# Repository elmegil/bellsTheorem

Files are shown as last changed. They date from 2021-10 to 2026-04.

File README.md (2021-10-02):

# bellsTheorem
[]

Bell's theorem is a proof that quantum physics is incompatible with local hidden variable theories.  The summary on Wikipedia is quite good if you’re interested in the quantum physics aspects of the theorem.

The proof is sometimes demonstrated by the use of multiple polarized lenses, as in this video:

https://www.youtube.com/watch?v=zcqZHYo7ONs&t=337s

What’s interesting is that with 3 or more polarized lenses, the behavior does not match what you might expect, namely that lens 1 reduces the light by a certain percentage, lens 2 reduces it further, and lens 3 reduces it even further, in a linear fashion.  If lens 3 and lens 1 are 90 degrees from each other, with nothing else involved, essentially no light gets through.  But if you insert lens 2 at a 45 degree angle to both of the others, suddenly there IS light getting through.  You’d expect that if 3 after 1 always blocks all the light, that would be true no matter what you put between the two.

A highly simplified explanation of this has to do with the fact that light is made up of photons, which are quantum objects.  Quantum objects behave probabilistically but ultimately are either there or not.  Photons going from lens 1 to lens 3 aren’t reduced in energy, they simply don’t pass both lenses.  However, going from one lens to one at 45 degrees only reduces the probability of photos passing by 50%.  In the process of going through, those photons then match the orientation of the second lens.  So when they get to a third lens, there is only a 45 degree angle difference there as well, and so 50% of the original 50%, or 25% of the original light, still passes through.

The rules for photons passing through polarized lenses basically are a probability that is determined entirely by the two lenses directly adjacent to the path of travel.  Any previous or subsequent lenses  aren’t considered except as a chained operation.  So with lens 1 at 0 degrees, lens 2 at 45, and lens 3 at 90 degrees (or 45 degrees from lens 2), the overall probability of a photon going from the start to the finish is 50% x 50%, or 25%.

Making things slightly weirder, the probabilities aren’t linear.  They follow a cosine squared relationship.  A photon passing through a pair of lenses at 22.5 degrees from each other is considerably more likely to pass through than the linear expectation of 75%.  In fact it’s about 85%.

============================================================================

Nyles Miszczyk on Facebook asked whether there were any modules that could process control voltages in this way.  There do not appear to be, but the idea was intriguing enough to give it a shot.  And that’s where this module comes from.

# Operational Notes

There is a single input voltage to be processed, which is normalled to +12V.  There are 4 encoders which represent the relative positions of four lenses, first to a “main” lens behind them all, and then relative to each other.  They’re arranged in a square pattern, and the input “light” (really the voltage) is processed as it goes through a single lens at 0 degrees, and then each subsequent lens.  Each of the combinations of lenses has a related output, so each of A, B, C, and D have an output that is only related to their individual angles relative to 0.  Each of AB, BC, CD, and DA has an output related to each of the intervening angles, as in the example described above; so for AB the voltage is reduced by whatever the probability is between 0 degrees and angle A, and then further reduced by whatever the probability is between the angles of A and B.  ABC, BCD, CDA, and DAB then follow the same rules for three lenses, and finally ABCD extends the process through all 4 lenses.

In addition to the encoders, each of the 4 lenses has a CV that is also related to its angle, added to the angle as set up by the encoder.  The 0 - 10V range maps to 180 degrees of rotation (positive only… need to consider doing otherwise).

On first power up, the lenses are reset to 0 degrees (but they should retain the last known state).  You can press each encoder to reset it to zero so that it’s at a known state.  If you do this by accident, pressing the encoder again takes you back to the saved state.  HOWEVER, if you zero out this way and then change things, you do do NOT save the new angle when you press again -- you just go back to the saved state, and pressing one more time takes you back to zero.

Voltage ranges: the current implementation limits inputs to 0-10V and each output will only generate 0-10V.  (and even that not very precisely).  A future revision may allow processing of bipolar input voltages, although this very likely will reduce the overall resolution.  Each input should be able to tolerate any normal Eurorack voltages outside this range (-12V to +12V), but they will be clamped at 0-10V.

Encoders:  the encoders’ positions are NOT directly mapped to the angle.  Most encoders only have about 24 steps (some have more, but none have 360 steps).  That did not seem to be a good resolution because each step would be 15 degrees.  I have mapped the encoders so that each step is 2 degrees of angle; this is why the press to reset is important so you can get back to a known angle. -- need to decide about CVs… 0 - 10V … is that 0 - 90 degrees?  0 - 180?  0 - 360?  Maybe consider 30 step encoders that do map the angle?  Is there any way to set up to display the angle, circle of LEDs on each encoder?  Is there sufficient space/bandwidth to update them?

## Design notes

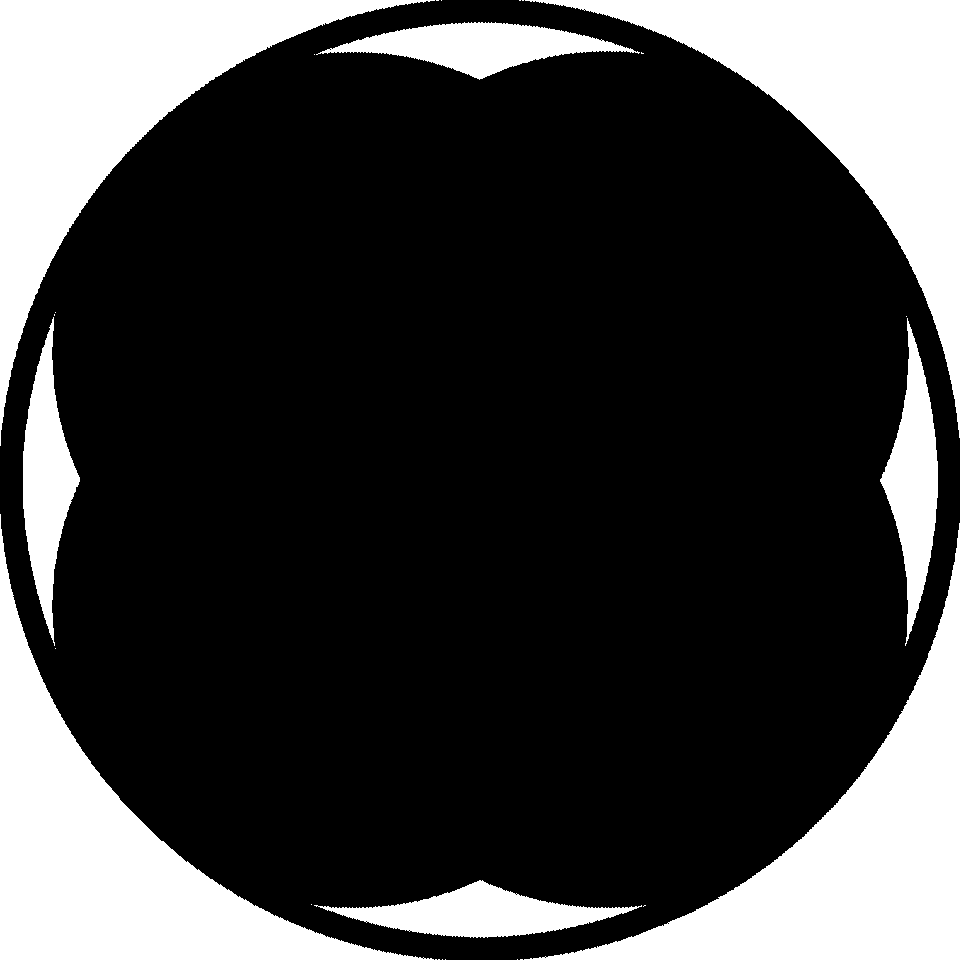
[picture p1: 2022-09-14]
images/bells-venn-trefoil-filled.bmp

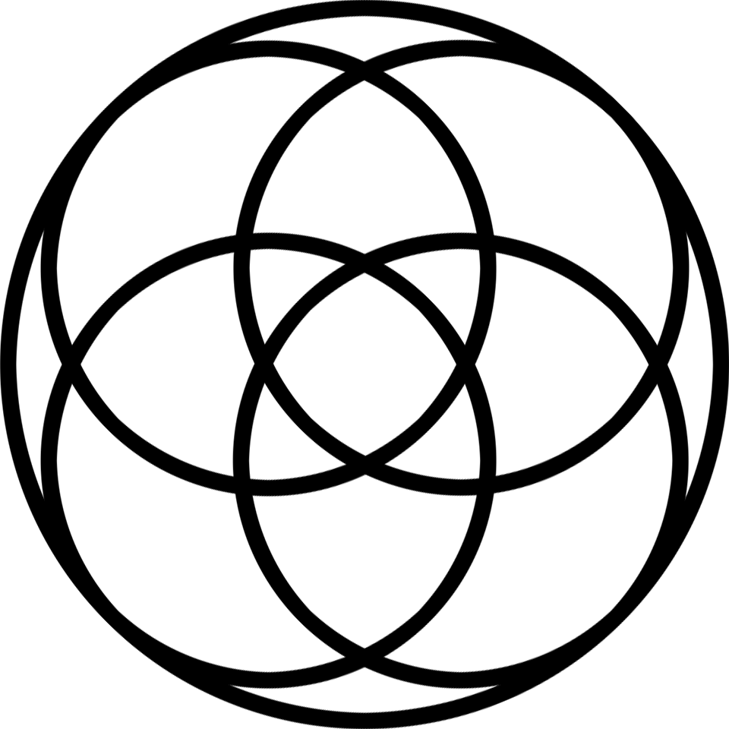
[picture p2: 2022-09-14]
images/bells-venn-trefoil.bmp

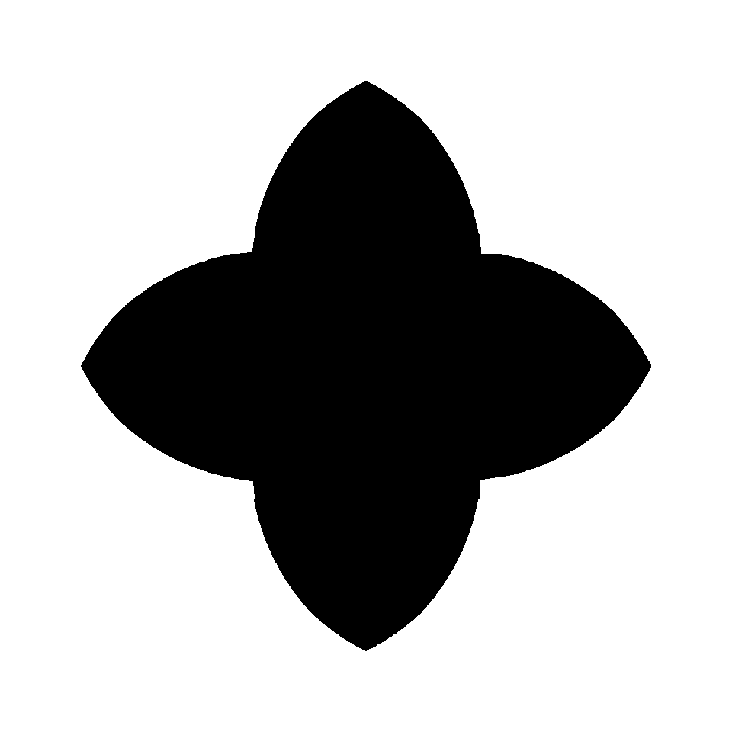
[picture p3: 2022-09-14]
images/bells-venn-trefoil-inside.bmp

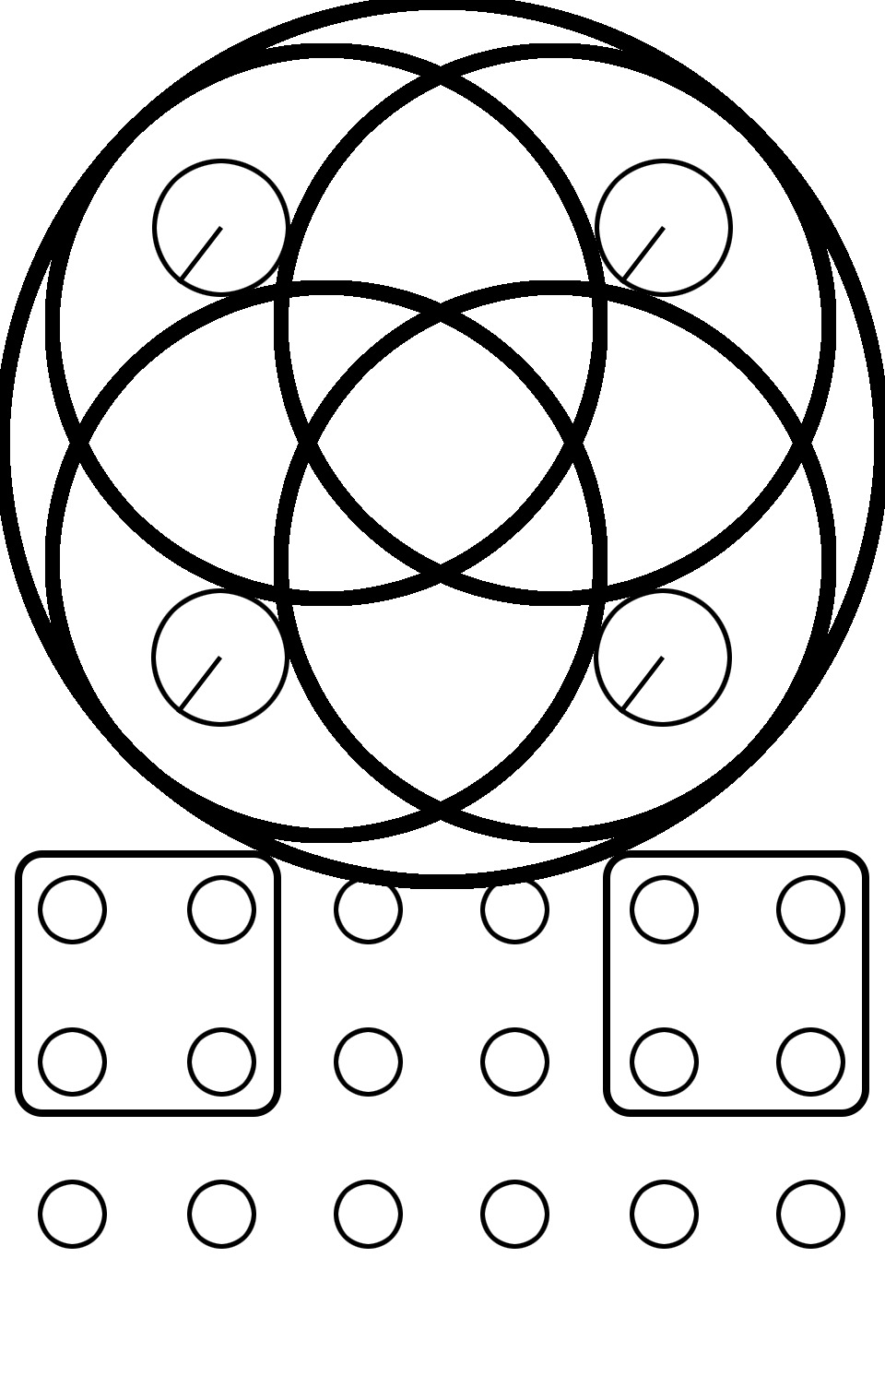
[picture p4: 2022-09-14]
images/bells-venn.jpg

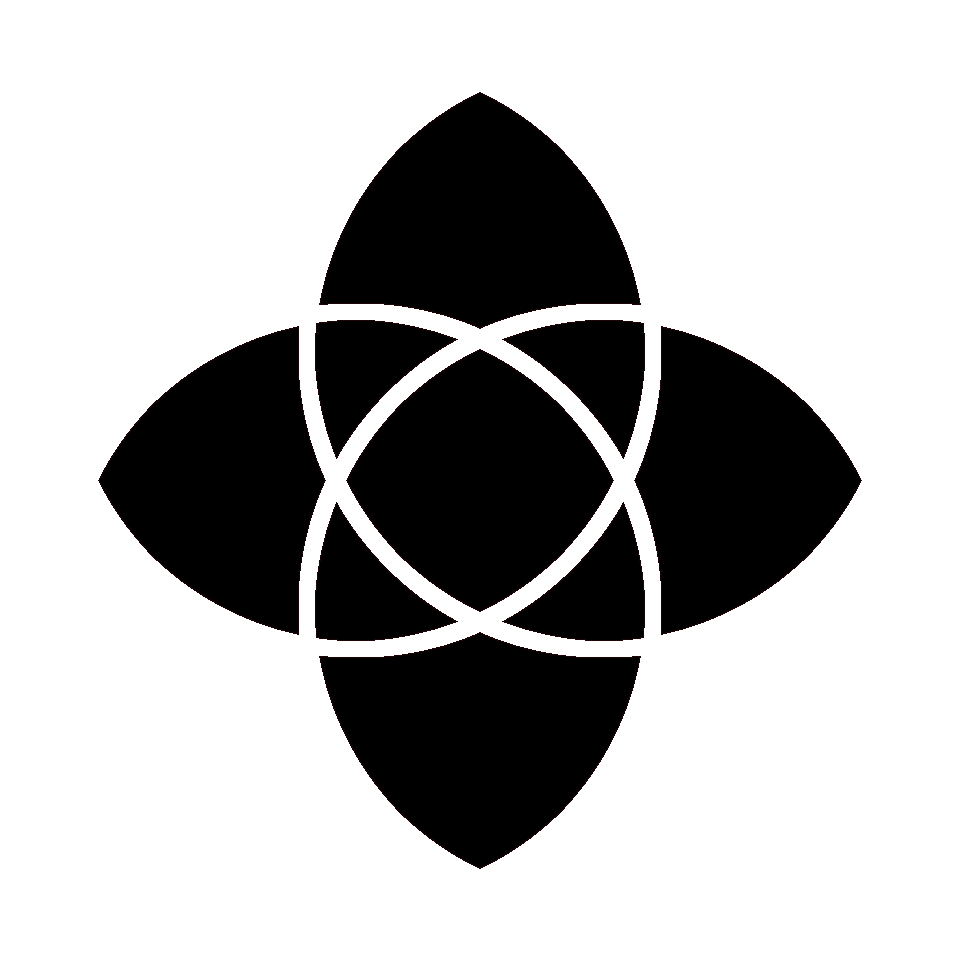
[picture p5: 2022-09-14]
images/bells-venn-trefoil-mask.bmp

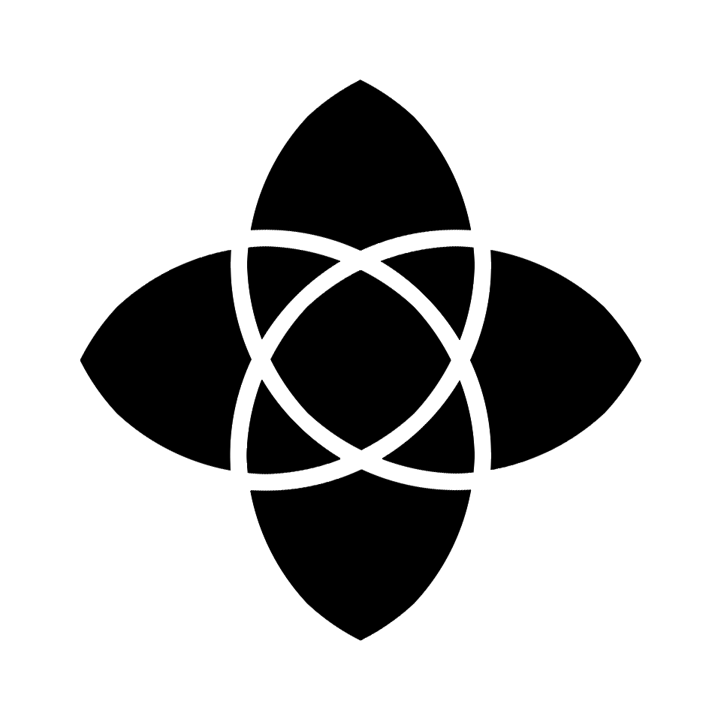
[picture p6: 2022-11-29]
images/bells-theorem-trefoil-mask2.bmp

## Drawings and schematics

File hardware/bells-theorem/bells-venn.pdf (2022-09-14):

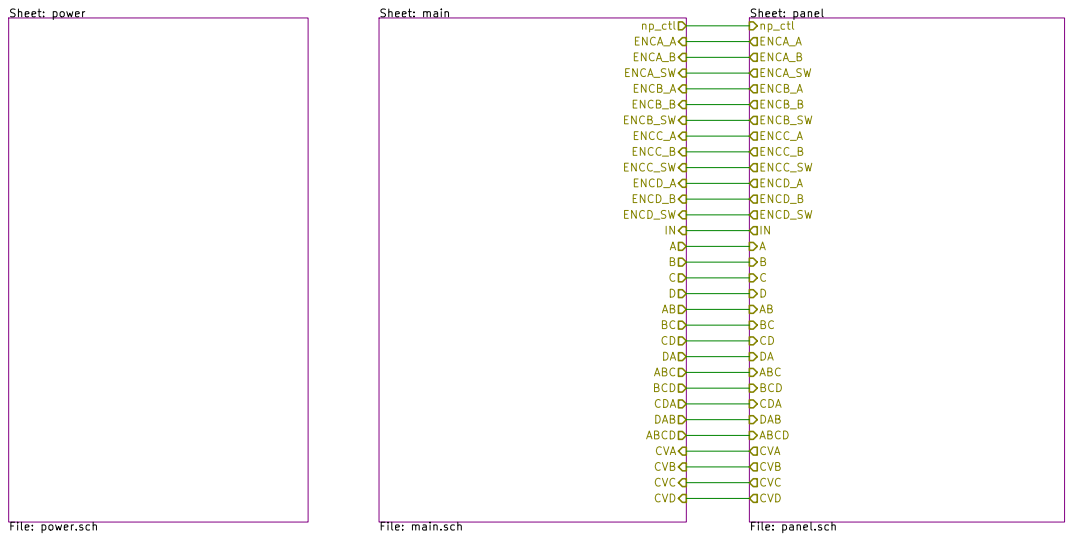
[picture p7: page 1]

File: bells-venn.sch Sheet: / re-layout attempting to use SMD and all in one PCB

Id: 1/8 Title: Hexinverter Postman

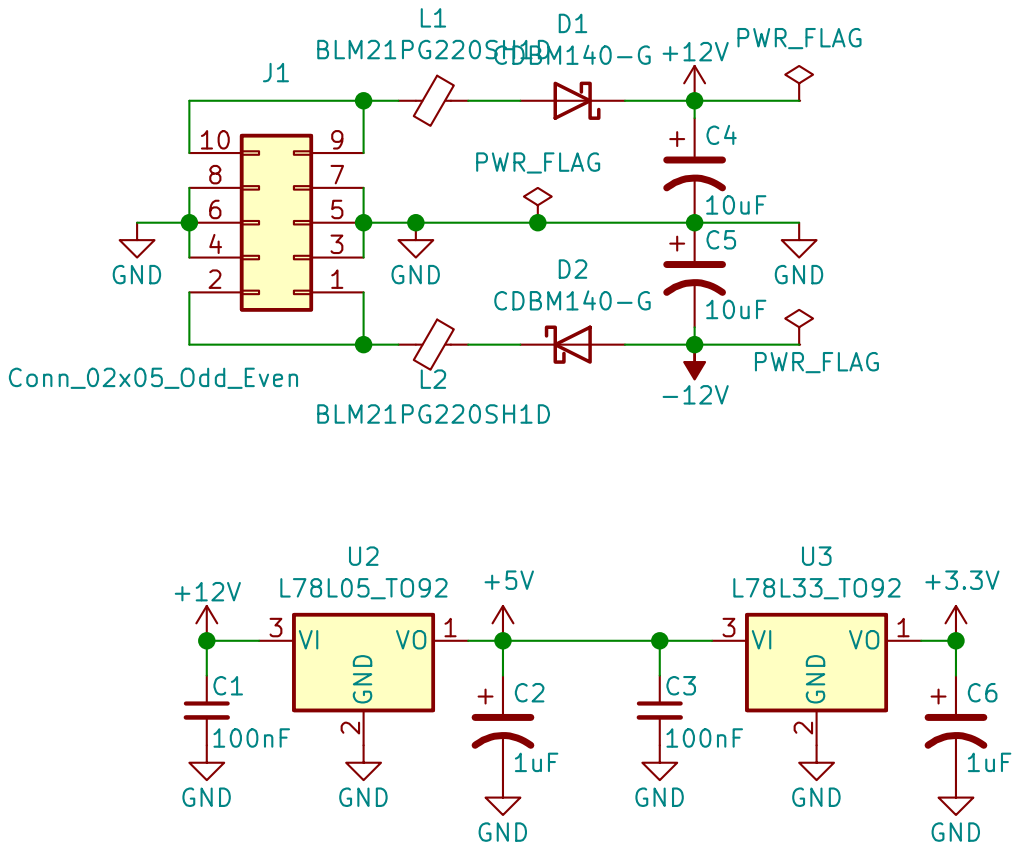
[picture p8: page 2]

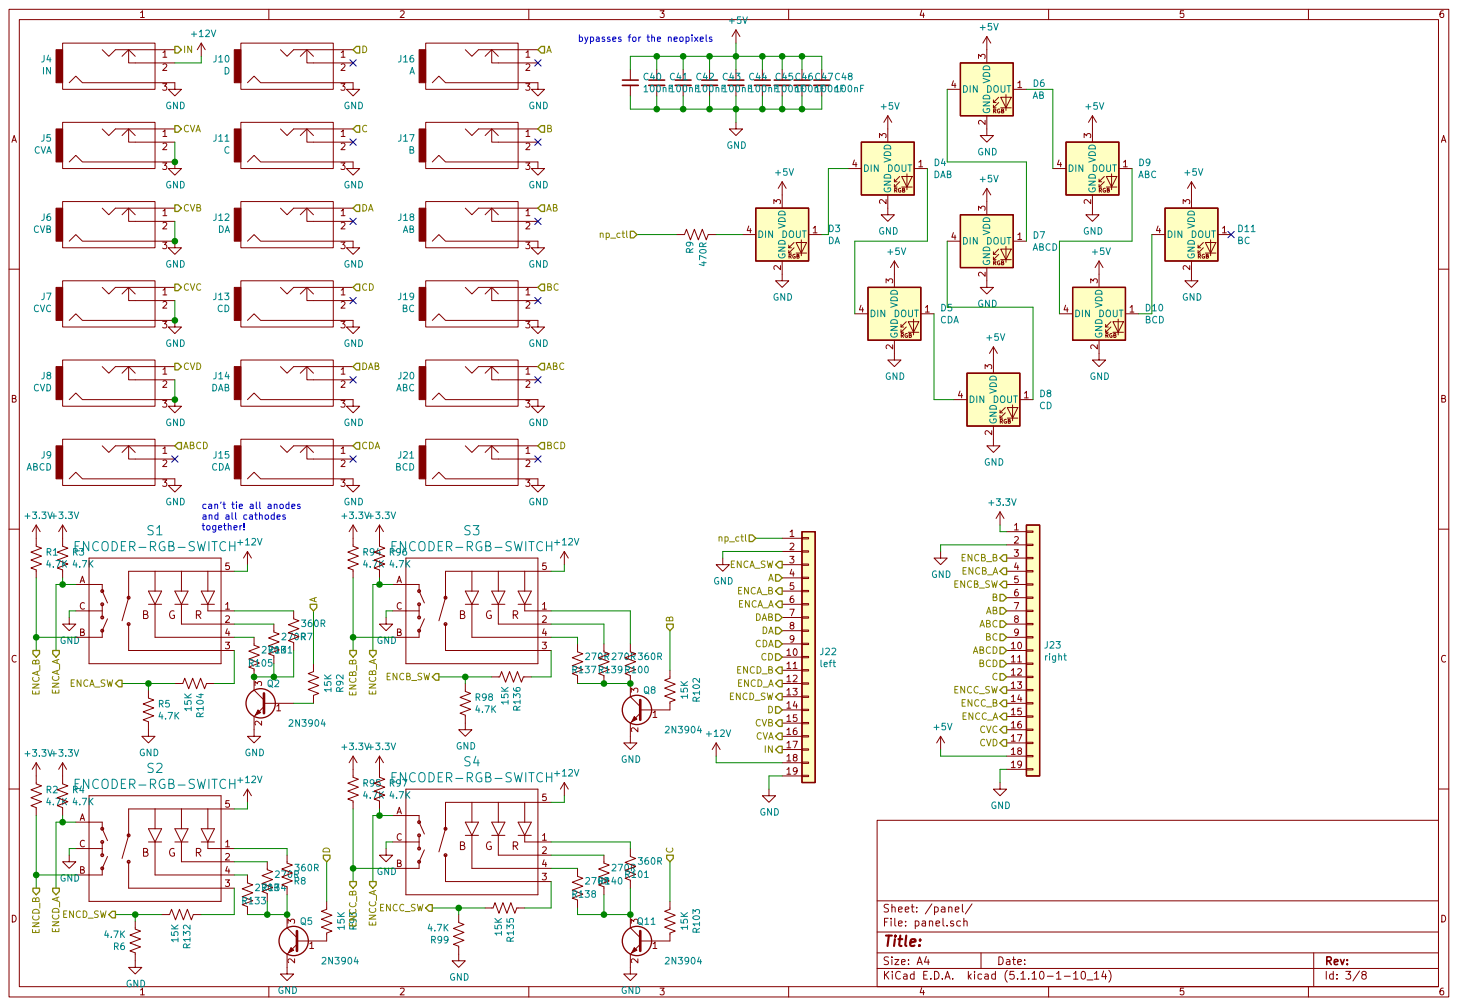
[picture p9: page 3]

cant tie all anodes and all cathodes

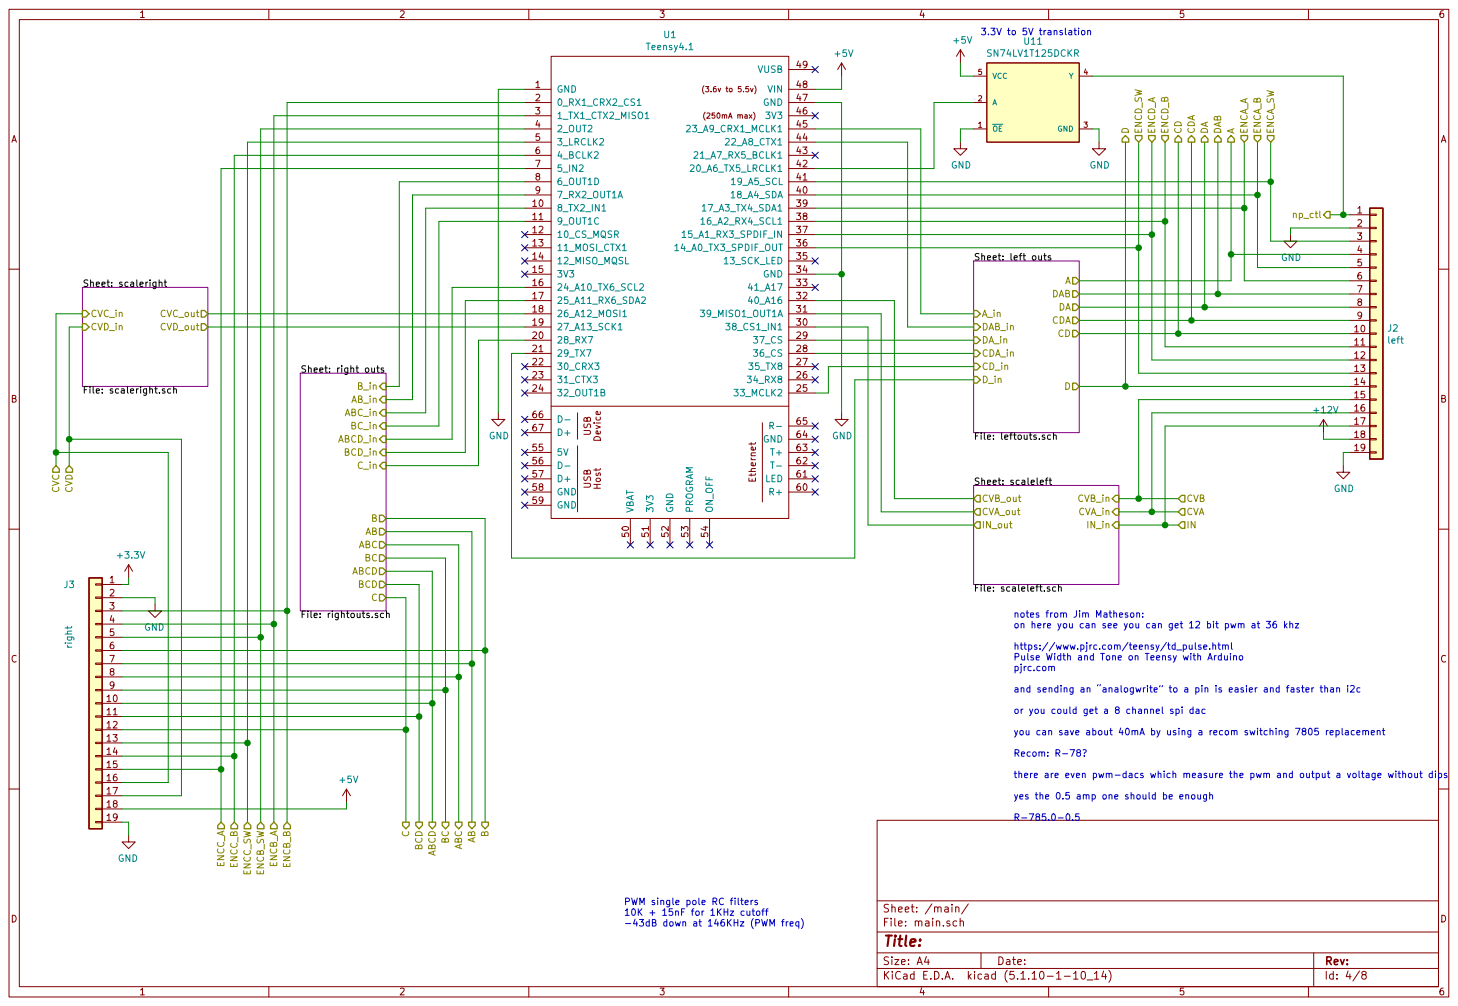
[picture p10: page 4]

7_RX2_OUT1A 9 GND 1

9_OUT1C 11 | | | left GND
6_OUT1D 8

10_CS_MQSR 12

25_A11_RX6_SDA2 17
26_A12_MOSI1 18
27_A13_SCK1 19
28_RX7 20
29_TX7 21

10
11

notes from Jim Matheson: on here you can see you can get 12 bit pwm at 36 khz

https://www.pjrc.com/teensy/td_pulse.html
Pulse Width and Tone on Teensy with Arduino
pjrc.com

12
13
14
15
16

and sending an analogwrite to a pin is easier and faster than i2c

or you could get a 8 channel spi dac

you can save about 40mA by using a recom switching 7805 replacement Recom: R-78?

there are even pwm-dacs which measure the pwm and output a voltage without dips

yes the 0.5 amp one should be enough R-785.0-0.5 PWM single pole RC filters 10K + 15nF for 1KHz cutoff -43dB down at 146KHz (PWM freq)

Id: 4/8 Title: File: main.sch Sheet: /main/

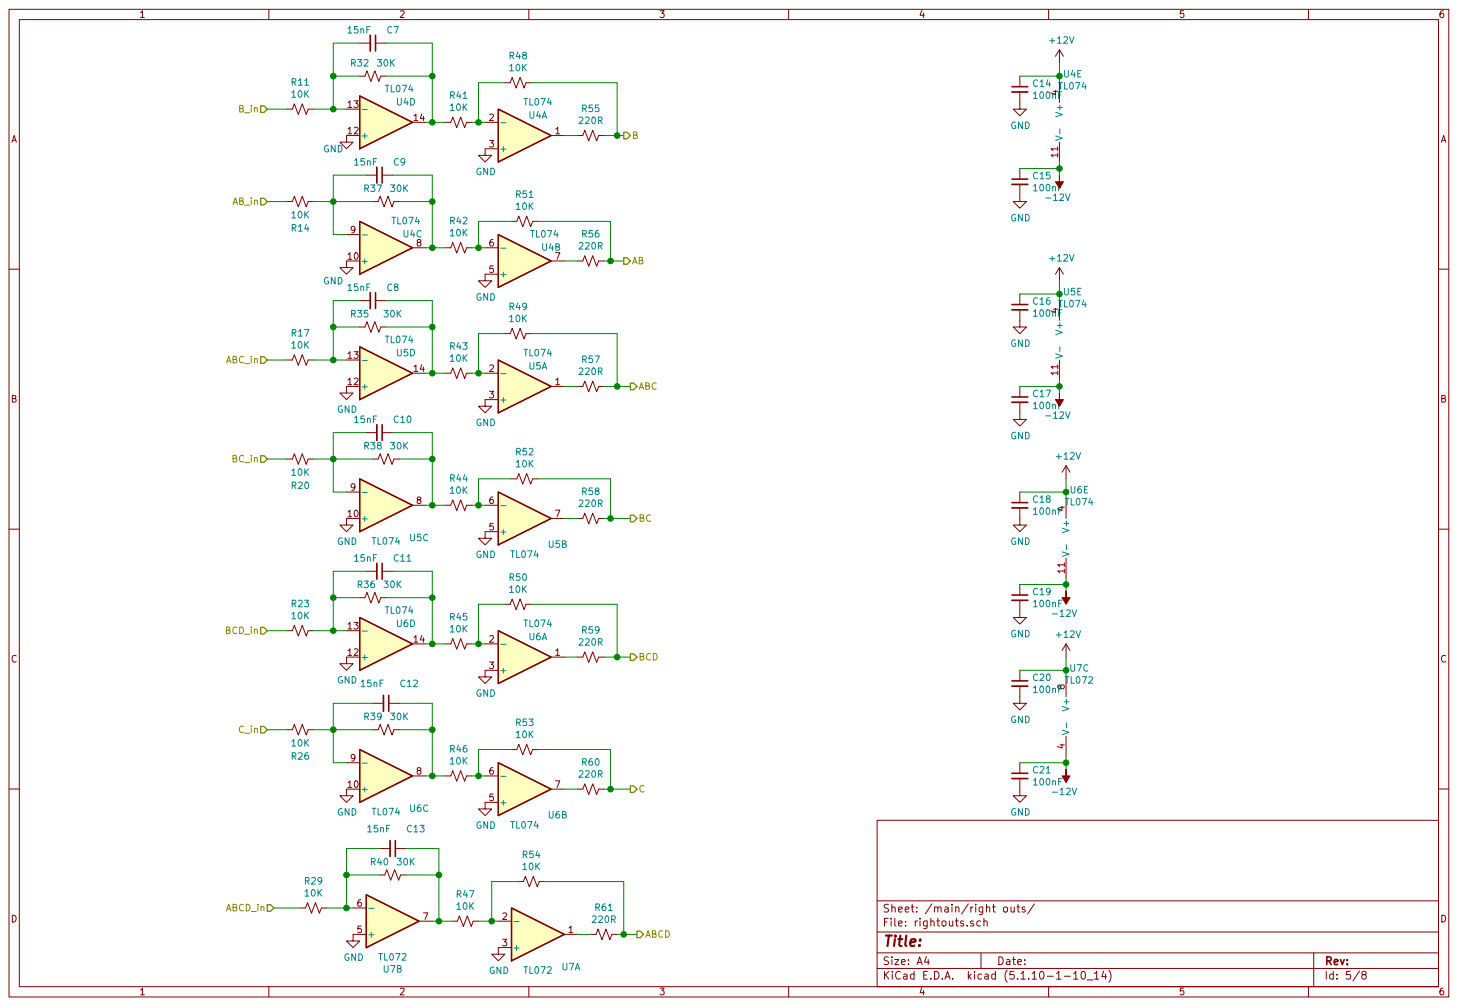
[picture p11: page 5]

Sheet: /main/right outs/ R50

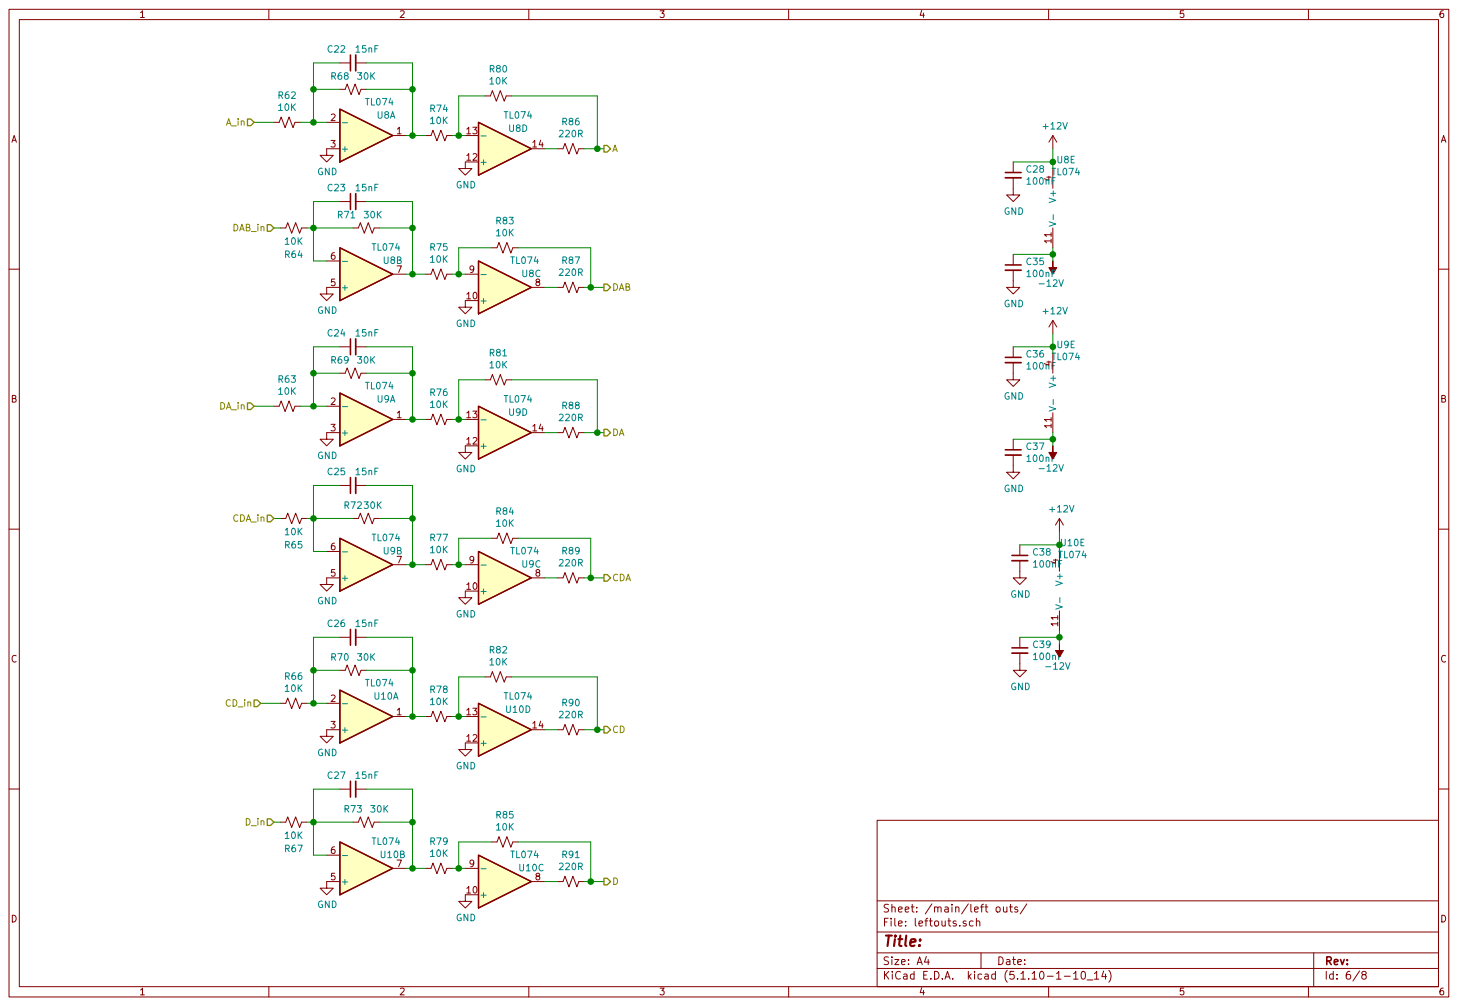
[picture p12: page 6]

Id: 6/8 Title: File: leftouts.sch Sheet: /main/left outs/ +

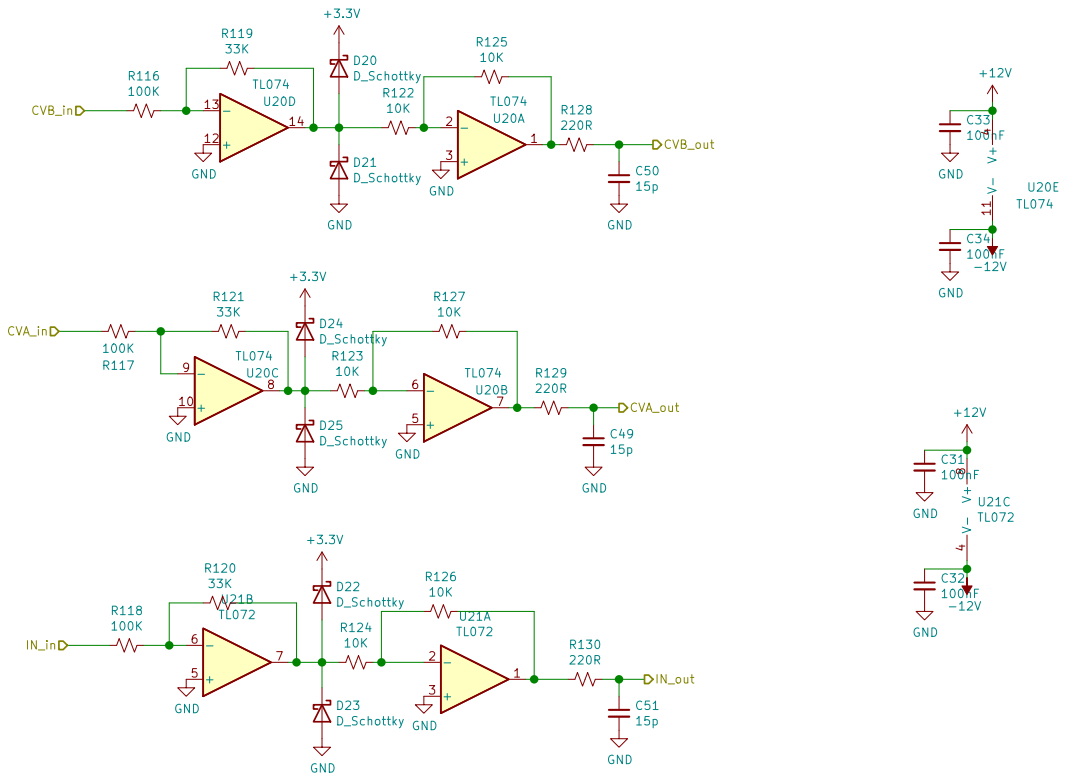
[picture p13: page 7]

Id: 7/8 Title: File: scaleleft.sch Sheet: /main/scaleleft/ +

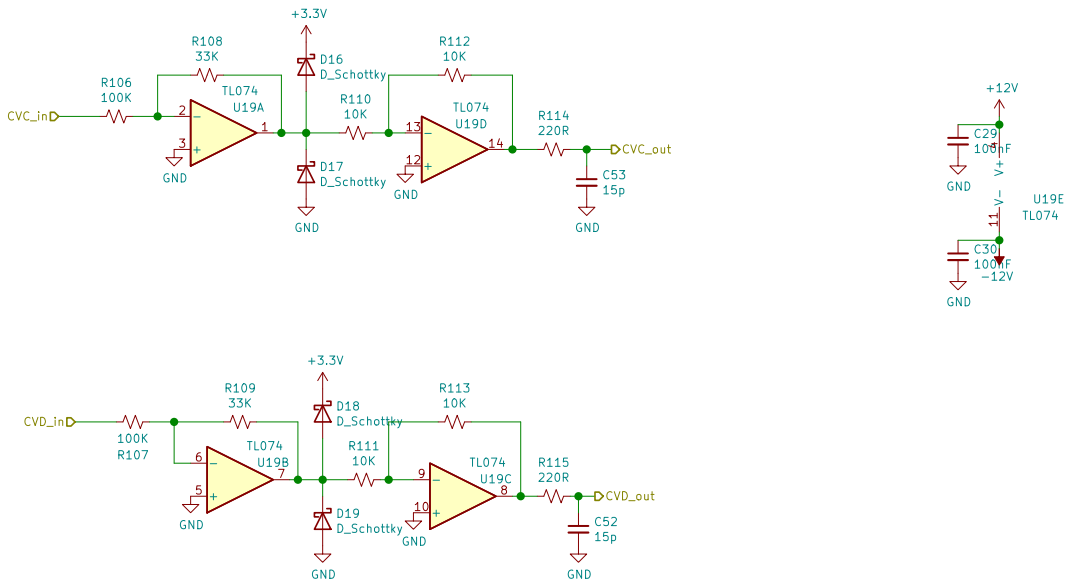
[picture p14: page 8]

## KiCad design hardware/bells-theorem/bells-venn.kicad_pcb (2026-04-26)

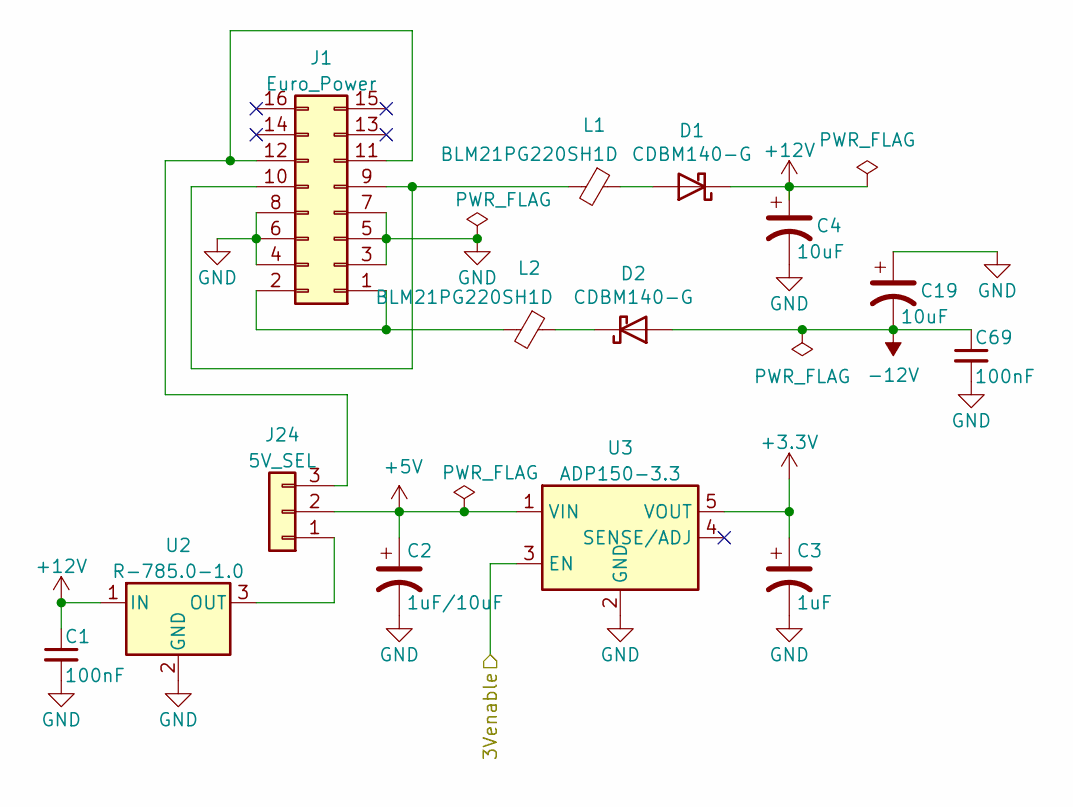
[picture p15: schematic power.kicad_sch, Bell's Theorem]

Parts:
C1, C69: 100nF; C_0805_2012Metric_Pad1.18x1.45mm_HandSolder
C2: 1uF/10uF; CP_Radial_D5.0mm_P2.50mm
C3: 1uF; CP_Radial_D5.0mm_P2.50mm
C4, C19: 10uF; CP_Radial_D5.0mm_P2.50mm
D1, D2: CDBM140-G; D_SMA-SMB_Universal_Handsoldering
J1: Euro_Power; IDC-Header_2x08_P2.54mm_Vertical
J24: 5V_SEL; PinHeader_1x03_P2.54mm_Vertical
L1, L2: BLM21PG220SH1D; L_0805_2012Metric_Pad1.15x1.40mm_HandSolder
U2: R-785.0-1.0; Converter_DCDC_RECOM_R-78E-0.5_THT
U3: ADP150-3.3; TSOT-23-5

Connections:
+3V3: C3.1, U3.5 (VOUT); also elsewhere on the board
+5V: C2.1, J24.2, U3.1 (VIN); also elsewhere on the board
+12V: C1.1, C4.1, D1.1 (K), U2.1 (IN); also elsewhere on the board
-12V: C19.2, C69.1, D2.2 (A); also elsewhere on the board
/main/3Venable: U3.3 (EN); also elsewhere on the board
GND: C1.2, C2.2, C3.2, C4.2, C19.1, C69.2, J1.3, J1.4, J1.5, J1.6, J1.7, J1.8, U2.2 (GND), U3.2 (GND); also elsewhere on the board
unnamed: D1.2 (A), L1.1
unnamed: D2.1 (K), L2.1
unnamed: J1.1, J1.2, L2.2
unnamed: J1.9, J1.10, L1.2
unnamed: J1.11, J1.12, J24.3
unnamed: J24.1, U2.3 (OUT)

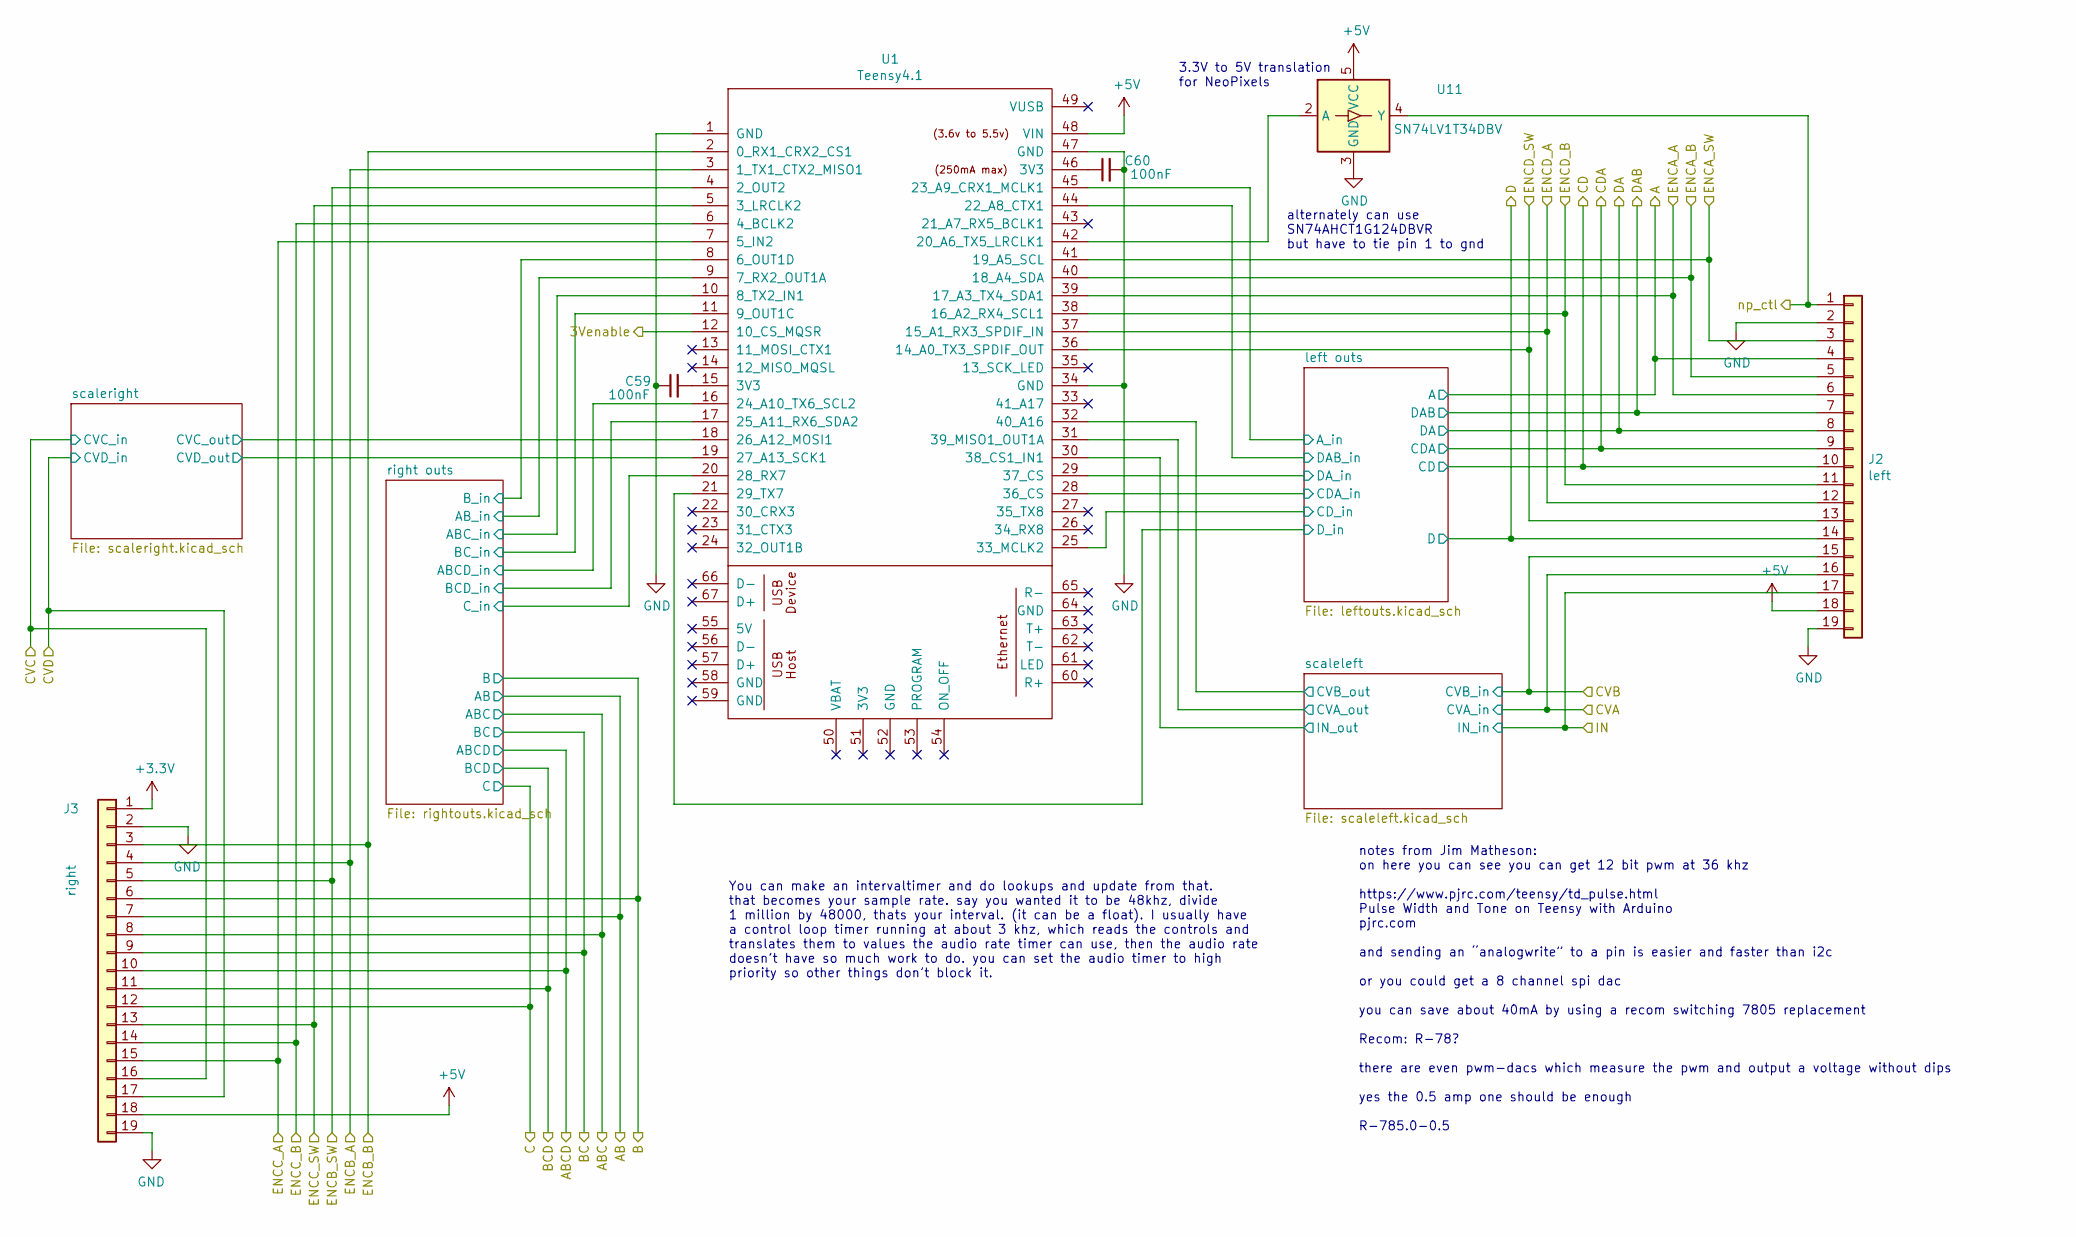
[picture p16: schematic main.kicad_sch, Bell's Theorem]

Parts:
C59, C60: 100nF; C_0805_2012Metric_Pad1.18x1.45mm_HandSolder
J2: left; PinSocket_1x19_P2.54mm_Vertical
J3: right; PinSocket_1x19_P2.54mm_Vertical
U1: Teensy4.1; Teensy41
U11: SN74LV1T34DBV; SOT-23-5

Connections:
+3V3: J3.1; also elsewhere on the board
+5V: J2.18, J3.18, U1.48 (VIN), U11.5 (VCC); also elsewhere on the board
/main/3Venable: U1.12 (10_CS_MQSR); also elsewhere on the board
/main/A: J2.4; also elsewhere on the board
/main/AB: J3.7; also elsewhere on the board
/main/ABC: J3.8; also elsewhere on the board
/main/ABCD: J3.10; also elsewhere on the board
/main/B: J3.6; also elsewhere on the board
/main/BC: J3.9; also elsewhere on the board
/main/BCD: J3.11; also elsewhere on the board
/main/C: J3.12; also elsewhere on the board
/main/CD: J2.10; also elsewhere on the board
/main/CDA: J2.9; also elsewhere on the board
/main/CVA: J2.16; also elsewhere on the board
/main/CVB: J2.15; also elsewhere on the board
/main/CVC: J3.16; also elsewhere on the board
/main/CVD: J3.17; also elsewhere on the board
/main/D: J2.14; also elsewhere on the board
/main/DA: J2.8; also elsewhere on the board
/main/DAB: J2.7; also elsewhere on the board
/main/ENCA_A: J2.6, U1.39 (17_A3_TX4_SDA1); also elsewhere on the board
/main/ENCA_B: J2.5, U1.40 (18_A4_SDA); also elsewhere on the board
/main/ENCA_SW: J2.3, U1.41 (19_A5_SCL); also elsewhere on the board
/main/ENCB_A: J3.4, U1.3 (1_TX1_CTX2_MISO1); also elsewhere on the board
/main/ENCB_B: J3.3, U1.2 (0_RX1_CRX2_CS1); also elsewhere on the board
/main/ENCB_SW: J3.5, U1.4 (2_OUT2); also elsewhere on the board
/main/ENCC_A: J3.15, U1.7 (5_IN2); also elsewhere on the board
/main/ENCC_B: J3.14, U1.6 (4_BCLK2); also elsewhere on the board
/main/ENCC_SW: J3.13, U1.5 (3_LRCLK2); also elsewhere on the board
/main/ENCD_A: J2.12, U1.37 (15_A1_RX3_SPDIF_IN); also elsewhere on the board
/main/ENCD_B: J2.11, U1.38 (16_A2_RX4_SCL1); also elsewhere on the board
/main/ENCD_SW: J2.13, U1.36 (14_A0_TX3_SPDIF_OUT); also elsewhere on the board
/main/IN: J2.17; also elsewhere on the board
/main/left outs/A_in: U1.45 (23_A9_CRX1_MCLK1); also elsewhere on the board
/main/left outs/CDA_in: U1.28 (36_CS); also elsewhere on the board
/main/left outs/CD_in: U1.25 (33_MCLK2); also elsewhere on the board
/main/left outs/DAB_in: U1.44 (22_A8_CTX1); also elsewhere on the board
/main/left outs/DA_in: U1.29 (37_CS); also elsewhere on the board
/main/left outs/D_in: U1.21 (29_TX7); also elsewhere on the board
/main/np_ctl: J2.1, U11.4 (Y); also elsewhere on the board
/main/right outs/ABCD_in: U1.16 (24_A10_TX6_SCL2); also elsewhere on the board
/main/right outs/ABC_in: U1.10 (8_TX2_IN1); also elsewhere on the board
/main/right outs/AB_in: U1.9 (7_RX2_OUT1A); also elsewhere on the board
/main/right outs/BCD_in: U1.17 (25_A11_RX6_SDA2); also elsewhere on the board
/main/right outs/BC_in: U1.11 (9_OUT1C); also elsewhere on the board
/main/right outs/B_in: U1.8 (6_OUT1D); also elsewhere on the board
/main/right outs/C_in: U1.20 (28_RX7); also elsewhere on the board
/main/scaleleft/CVA_out: U1.31 (39_MISO1_OUT1A); also elsewhere on the board
/main/scaleleft/CVB_out: U1.32 (40_A16); also elsewhere on the board
/main/scaleleft/IN_out: U1.30 (38_CS1_IN1); also elsewhere on the board
/main/scaleright/CVC_out: U1.18 (26_A12_MOSI1); also elsewhere on the board
/main/scaleright/CVD_out: U1.19 (27_A13_SCK1); also elsewhere on the board
GND: C59.1, C60.2, J2.2, J2.19, J3.2, J3.19, U1.1 (GND), U1.34 (GND), U1.47 (GND), U11.3 (GND); also elsewhere on the board
unnamed: C59.2, U1.15 (3V3)
unnamed: C60.1, U1.46 (3V3)
unnamed: U1.42 (20_A6_TX5_LRCLK1), U11.2 (A)

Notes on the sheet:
You can make an intervaltimer and do lookups and update from that. that becomes your sample rate. say you wanted it to be 48khz, divide 1 million by 48000, thats your interval. (it can be a float). I usually have a control loop timer running at about 3 khz, which reads the controls and translates t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
notes from Jim Matheson: on here you can see you can get 12 bit pwm at 36 khz https://www.pjrc.com/teensy/td_pulse.html Pulse Width and Tone on Teensy with Arduino pjrc.com and sending an “analogwrite” to a pin is easier and faster than i2c or you could get a 8 channel spi dac you can save about 40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
3.3V to 5V translation for NeoPixels
alternately can use SN74AHCT1G124DBVR but have to tie pin 1 to gnd

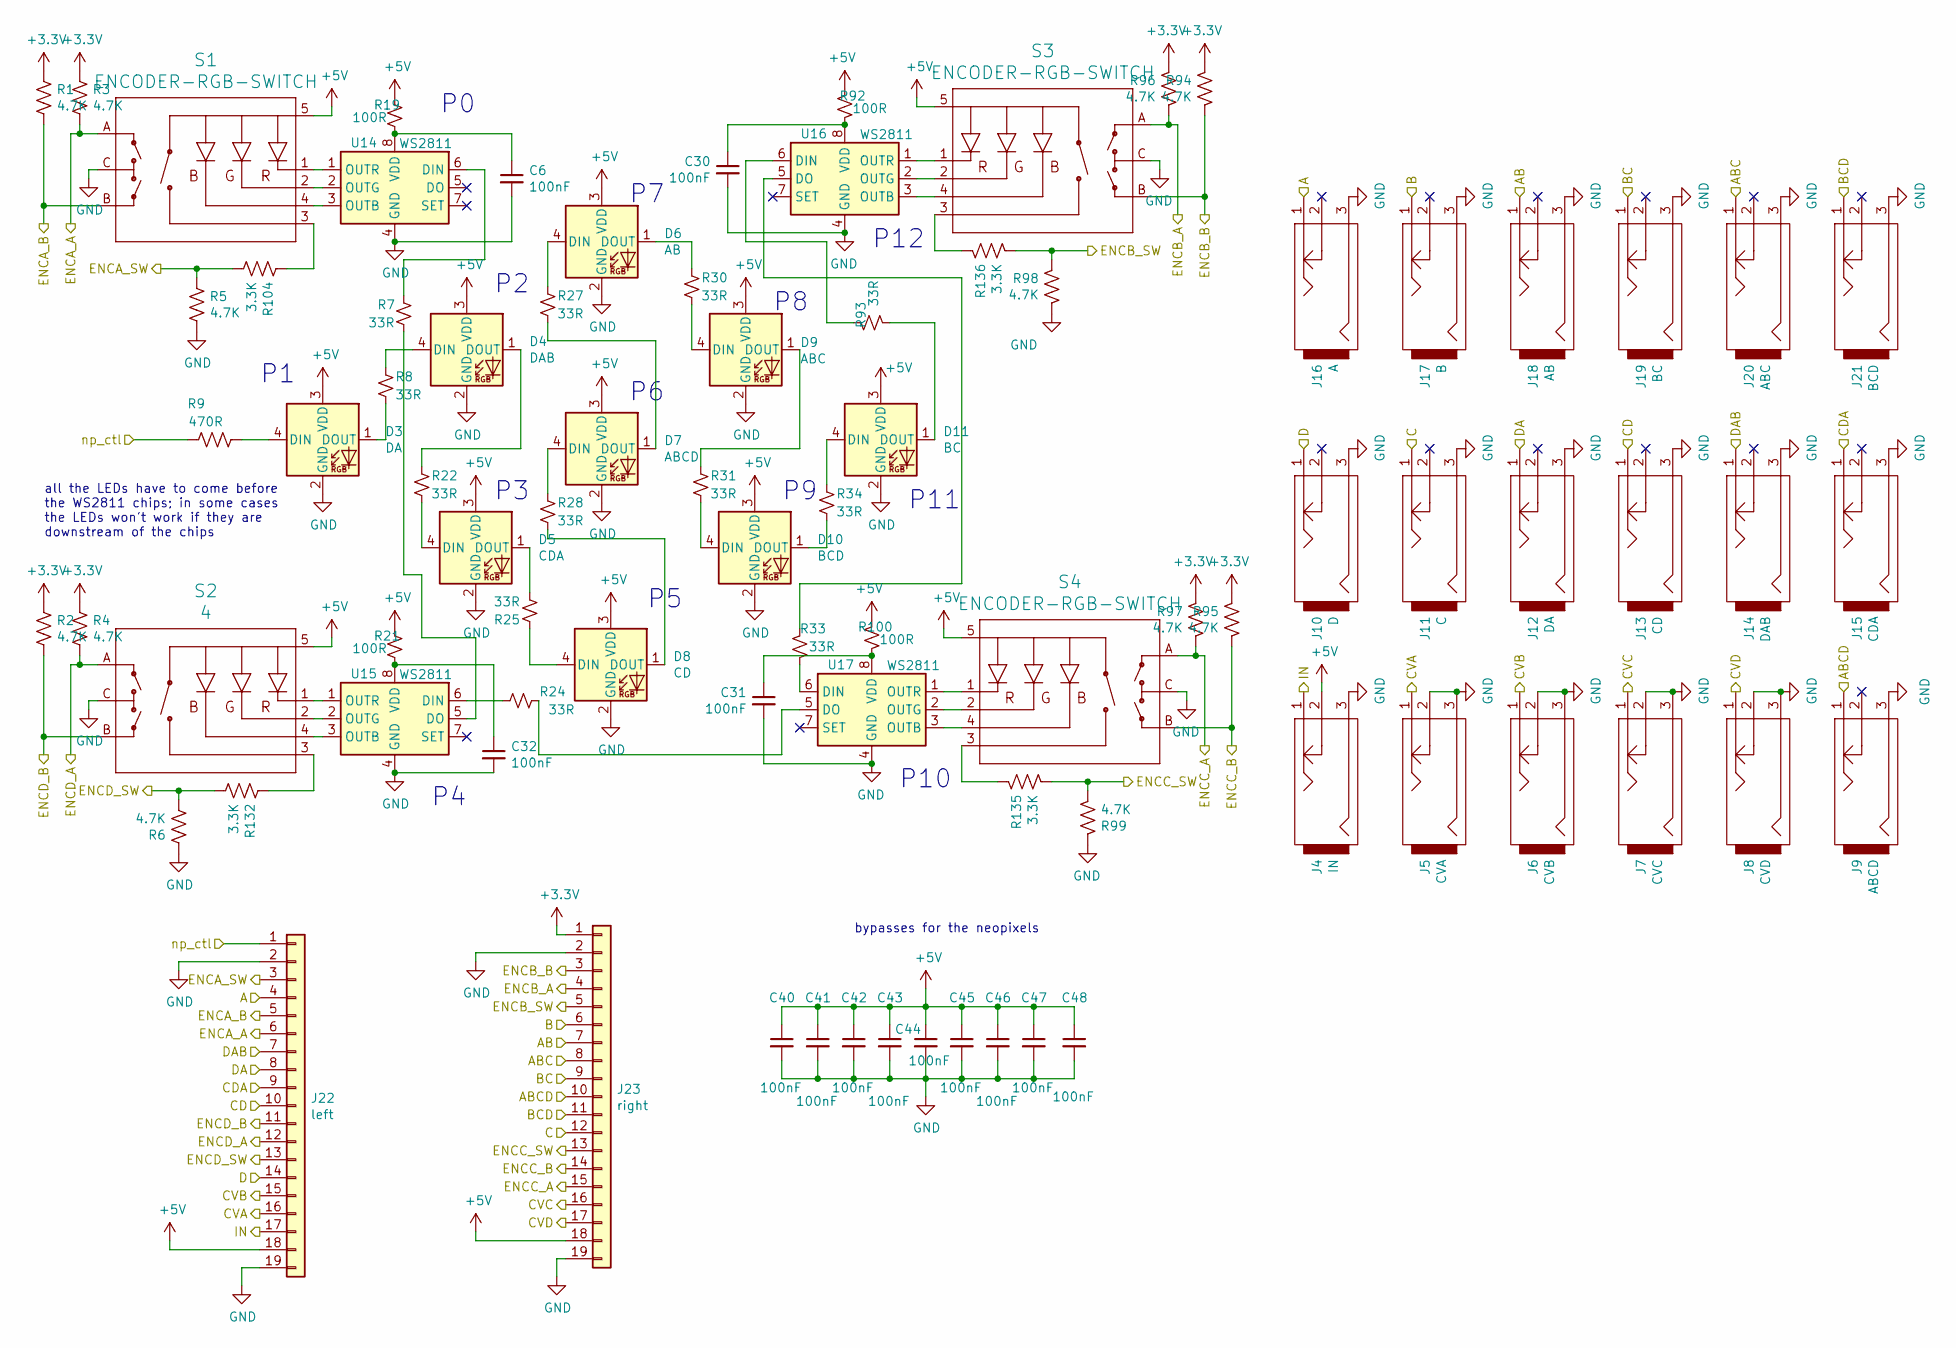
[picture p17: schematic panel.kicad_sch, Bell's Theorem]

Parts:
C6, C30, C31, C32, C40, C41, C42, C43, C44, C45, C46, C47, C48: 100nF; C_0805_2012Metric_Pad1.18x1.45mm_HandSolder
D3: DA; LED_D5.0mm-4_RGB
D4: DAB; LED_D5.0mm-4_RGB
D5: CDA; LED_D5.0mm-4_RGB
D6: AB; LED_D5.0mm-4_RGB
D7: ABCD; LED_D5.0mm-4_RGB
D8: CD; LED_D5.0mm-4_RGB
D9: ABC; LED_D5.0mm-4_RGB
D10: BCD; LED_D5.0mm-4_RGB
D11: BC; LED_D5.0mm-4_RGB
J4: IN; thonkiconn
J5: CVA; thonkiconn
J6: CVB; thonkiconn
J7: CVC; thonkiconn
J8: CVD; thonkiconn
J9: ABCD; thonkiconn
J10: D; thonkiconn
J11: C; thonkiconn
J12: DA; thonkiconn
J13: CD; thonkiconn
J14: DAB; thonkiconn
J15: CDA; thonkiconn
J16: A; thonkiconn
J17: B; thonkiconn
J18: AB; thonkiconn
J19: BC; thonkiconn
J20: ABC; thonkiconn
J21: BCD; thonkiconn
J22: left; PinHeader_1x19_P2.54mm_Vertical
J23: right; PinHeader_1x19_P2.54mm_Vertical
R1, R2, R3, R4, R5, R6, R94, R95, R96, R97, R98, R99: 4.7K; R_0805_2012Metric_Pad1.20x1.40mm_HandSolder
R7, R8, R22, R24, R25, R27, R28, R30, R31, R33, R34, R93: 33R; R_0805_2012Metric_Pad1.20x1.40mm_HandSolder
R9: 470R; R_0805_2012Metric_Pad1.20x1.40mm_HandSolder
R19, R21, R92, R100: 100R; R_0805_2012Metric_Pad1.20x1.40mm_HandSolder
R104, R132, R135, R136: 3.3K; R_0805_2012Metric_Pad1.20x1.40mm_HandSolder
S1, S3, S4: ENCODER-RGB-SWITCH; ENCODER_LED_3_KIT
S2: 4; ENCODER_LED_3_KIT
U14, U15, U16, U17: WS2811; SOIC-8_3.9x4.9mm_P1.27mm

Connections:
+3V3: J23.1, R1.1, R2.1, R3.1, R4.1, R94.1, R95.1, R96.1, R97.1; also elsewhere on the board
+5V: C40.1, C41.1, C42.1, C43.1, C44.1, C45.1, C46.1, C47.1, C48.1, D3.3 (VDD), D4.3 (VDD), D5.3 (VDD), D6.3 (VDD), D7.3 (VDD), D8.3 (VDD), D9.3 (VDD), D10.3 (VDD), D11.3 (VDD), J4.2, J22.18, J23.18, R19.1, R21.1, R92.1, R100.1, S1.5 (+), S2.5 (+), S3.5 (+), S4.5 (+); also elsewhere on the board
/main/A: J16.1, J22.4; also elsewhere on the board
/main/AB: J18.1, J23.7; also elsewhere on the board
/main/ABC: J20.1, J23.8; also elsewhere on the board
/main/ABCD: J9.1, J23.10; also elsewhere on the board
/main/B: J17.1, J23.6; also elsewhere on the board
/main/BC: J19.1, J23.9; also elsewhere on the board
/main/BCD: J21.1, J23.11; also elsewhere on the board
/main/C: J11.1, J23.12; also elsewhere on the board
/main/CD: J13.1, J22.10; also elsewhere on the board
/main/CDA: J15.1, J22.9; also elsewhere on the board
/main/CVA: J5.1, J22.16; also elsewhere on the board
/main/CVB: J6.1, J22.15; also elsewhere on the board
/main/CVC: J7.1, J23.16; also elsewhere on the board
/main/CVD: J8.1, J23.17; also elsewhere on the board
/main/D: J10.1, J22.14; also elsewhere on the board
/main/DA: J12.1, J22.8; also elsewhere on the board
/main/DAB: J14.1, J22.7; also elsewhere on the board
/main/ENCA_A: J22.6, R3.2, S1.A; also elsewhere on the board
/main/ENCA_B: J22.5, R1.2, S1.B; also elsewhere on the board
/main/ENCA_SW: J22.3, R5.1, R104.2; also elsewhere on the board
/main/ENCB_A: J23.4, R96.2, S3.A; also elsewhere on the board
/main/ENCB_B: J23.3, R94.2, S3.B; also elsewhere on the board
/main/ENCB_SW: J23.5, R98.1, R136.2; also elsewhere on the board
/main/ENCC_A: J23.15, R97.2, S4.A; also elsewhere on the board
/main/ENCC_B: J23.14, R95.2, S4.B; also elsewhere on the board
/main/ENCC_SW: J23.13, R99.2, R135.2; also elsewhere on the board
/main/ENCD_A: J22.12, R4.2, S2.A; also elsewhere on the board
/main/ENCD_B: J22.11, R2.2, S2.B; also elsewhere on the board
/main/ENCD_SW: J22.13, R6.2, R132.2; also elsewhere on the board
/main/IN: J4.1, J22.17; also elsewhere on the board
/main/np_ctl: J22.1, R9.1; also elsewhere on the board
GND: C6.2, C30.2, C31.2, C32.2, C40.2, C41.2, C42.2, C43.2, C44.2, C45.2, C46.2, C47.2, C48.2, D3.2 (GND), D4.2 (GND), D5.2 (GND), D6.2 (GND), D7.2 (GND), D8.2 (GND), D9.2 (GND), D10.2 (GND), D11.2 (GND), J4.3, J5.2, J5.3, J6.2, J6.3, J7.2, J7.3, J8.2, J8.3, J9.3, J10.3, J11.3, J12.3, J13.3, J14.3, J15.3, J16.3, J17.3, J18.3, J19.3, J20.3, J21.3, J22.2, J22.19, J23.2, J23.19, R5.2, R6.1, R98.2, R99.1, S1.C, S2.C, S3.C, S4.C, U14.4 (GND), U15.4 (GND), U16.4 (GND), U17.4 (GND); also elsewhere on the board
unnamed: C6.1, R19.2, U14.8 (VDD)
unnamed: C30.1, R92.2, U16.8 (VDD)
unnamed: C31.1, R100.2, U17.8 (VDD)
unnamed: C32.1, R21.2, U15.8 (VDD)
unnamed: D3.1 (DOUT), R8.2
unnamed: D3.4 (DIN), R9.2
unnamed: D4.1 (DOUT), R22.1
unnamed: D4.4 (DIN), R8.1
unnamed: D5.1 (DOUT), R25.2
unnamed: D5.4 (DIN), R22.2
unnamed: D6.1 (DOUT), R30.1
unnamed: D6.4 (DIN), R27.1
unnamed: D7.1 (DOUT), R27.2
unnamed: D7.4 (DIN), R28.1
unnamed: D8.1 (DOUT), R28.2
unnamed: D8.4 (DIN), R25.1
unnamed: D9.1 (DOUT), R31.1
unnamed: D9.4 (DIN), R30.2
unnamed: D10.1 (DOUT), R34.2
unnamed: D10.4 (DIN), R31.2
unnamed: D11.1 (DOUT), R93.2
unnamed: D11.4 (DIN), R34.1
unnamed: R7.1, U14.6 (DIN)
unnamed: R7.2, U15.5 (DO)
unnamed: R24.1, U17.5 (DO)
unnamed: R24.2, U15.6 (DIN)
unnamed: R33.1, U16.5 (DO)
unnamed: R33.2, U17.6 (DIN)
unnamed: R93.1, U16.6 (DIN)
unnamed: R104.1, S1.3 (SW)
unnamed: R132.1, S2.3 (SW)
unnamed: R135.1, S4.3 (SW)
unnamed: R136.1, S3.3 (SW)
unnamed: S1.1 (-R), U14.1 (OUTR)
unnamed: S1.2 (-G), U14.2 (OUTG)
unnamed: S1.4 (-B), U14.3 (OUTB)
unnamed: S2.1 (-R), U15.1 (OUTR)
unnamed: S2.2 (-G), U15.2 (OUTG)
unnamed: S2.4 (-B), U15.3 (OUTB)
unnamed: S3.1 (-R), U16.1 (OUTR)
unnamed: S3.2 (-G), U16.2 (OUTG)
unnamed: S3.4 (-B), U16.3 (OUTB)
unnamed: S4.1 (-R), U17.1 (OUTR)
unnamed: S4.2 (-G), U17.2 (OUTG)
unnamed: S4.4 (-B), U17.3 (OUTB)

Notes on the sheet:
bypasses for the neopixels
all the LEDs have to come before the WS2811 chips; in some cases the LEDs won't work if they are downstream of the chips
P12
P11
P10

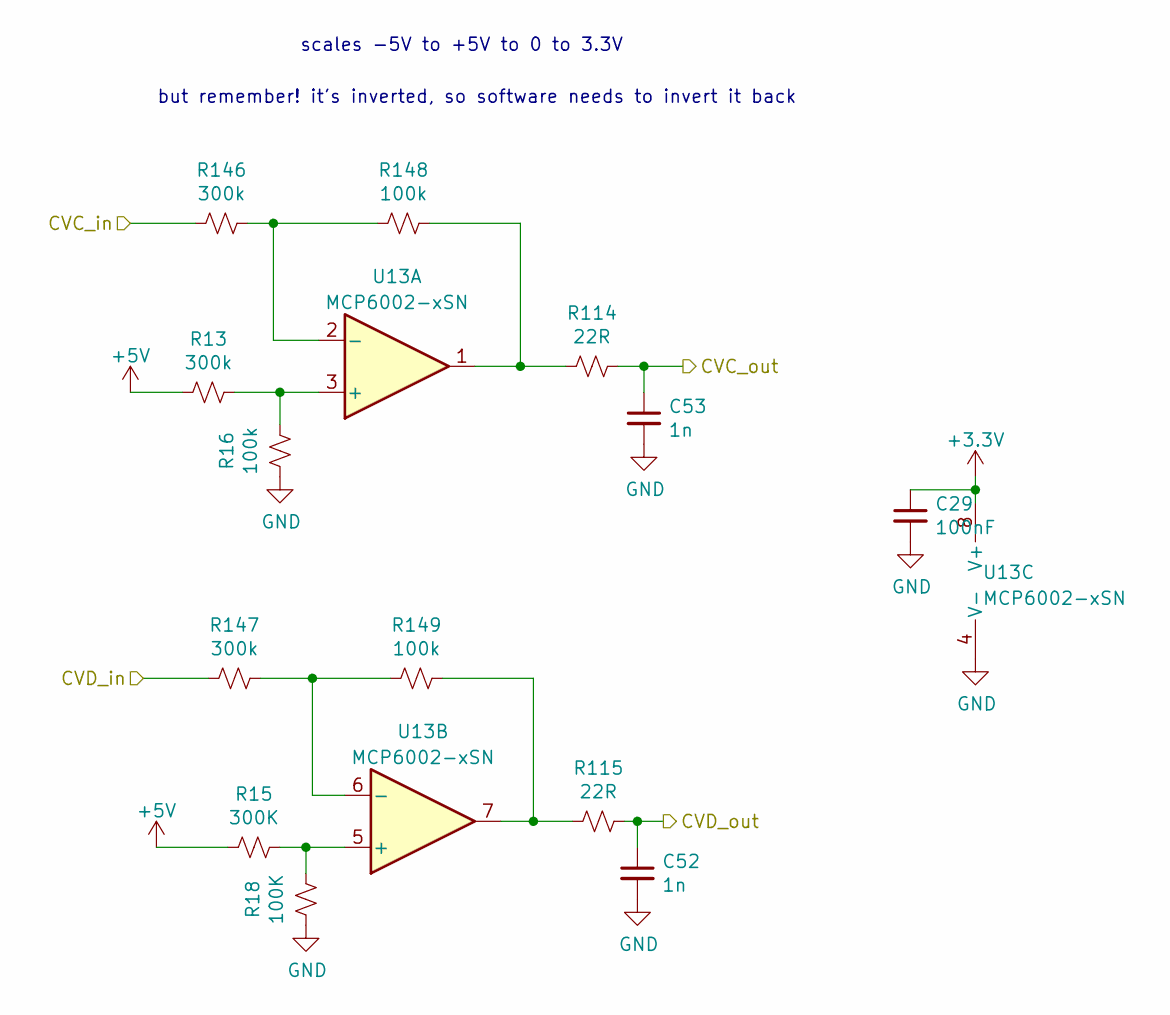
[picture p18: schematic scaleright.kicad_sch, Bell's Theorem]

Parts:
C29: 100nF; C_0805_2012Metric_Pad1.18x1.45mm_HandSolder
C52, C53: 1n; C_0805_2012Metric_Pad1.18x1.45mm_HandSolder
R13, R146, R147: 300k; R_0805_2012Metric_Pad1.20x1.40mm_HandSolder
R15: 300K; R_0805_2012Metric_Pad1.20x1.40mm_HandSolder
R16, R148, R149: 100k; R_0805_2012Metric_Pad1.20x1.40mm_HandSolder
R18: 100K; R_0805_2012Metric_Pad1.20x1.40mm_HandSolder
R114, R115: 22R; R_0805_2012Metric_Pad1.20x1.40mm_HandSolder
U13: MCP6002-xSN; SOIC-8_3.9x4.9mm_P1.27mm

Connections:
+3V3: C29.1, U13.8 (V+); also elsewhere on the board
+5V: R13.2, R15.2; also elsewhere on the board
/main/CVC: R146.2; also elsewhere on the board
/main/CVD: R147.2; also elsewhere on the board
/main/scaleright/CVC_out: C53.1, R114.1; also elsewhere on the board
/main/scaleright/CVD_out: C52.1, R115.1; also elsewhere on the board
GND: C29.2, C52.2, C53.2, R16.2, R18.2, U13.4 (V-); also elsewhere on the board
unnamed: R13.1, R16.1, U13.3 (+)
unnamed: R15.1, R18.1, U13.5 (+)
unnamed: R114.2, R148.1, U13.1
unnamed: R115.2, R149.1, U13.7
unnamed: R146.1, R148.2, U13.2 (-)
unnamed: R147.1, R149.2, U13.6 (-)

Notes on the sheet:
but remember! it's inverted, so software needs to invert it back
scales -5V to +5V to 0 to 3.3V

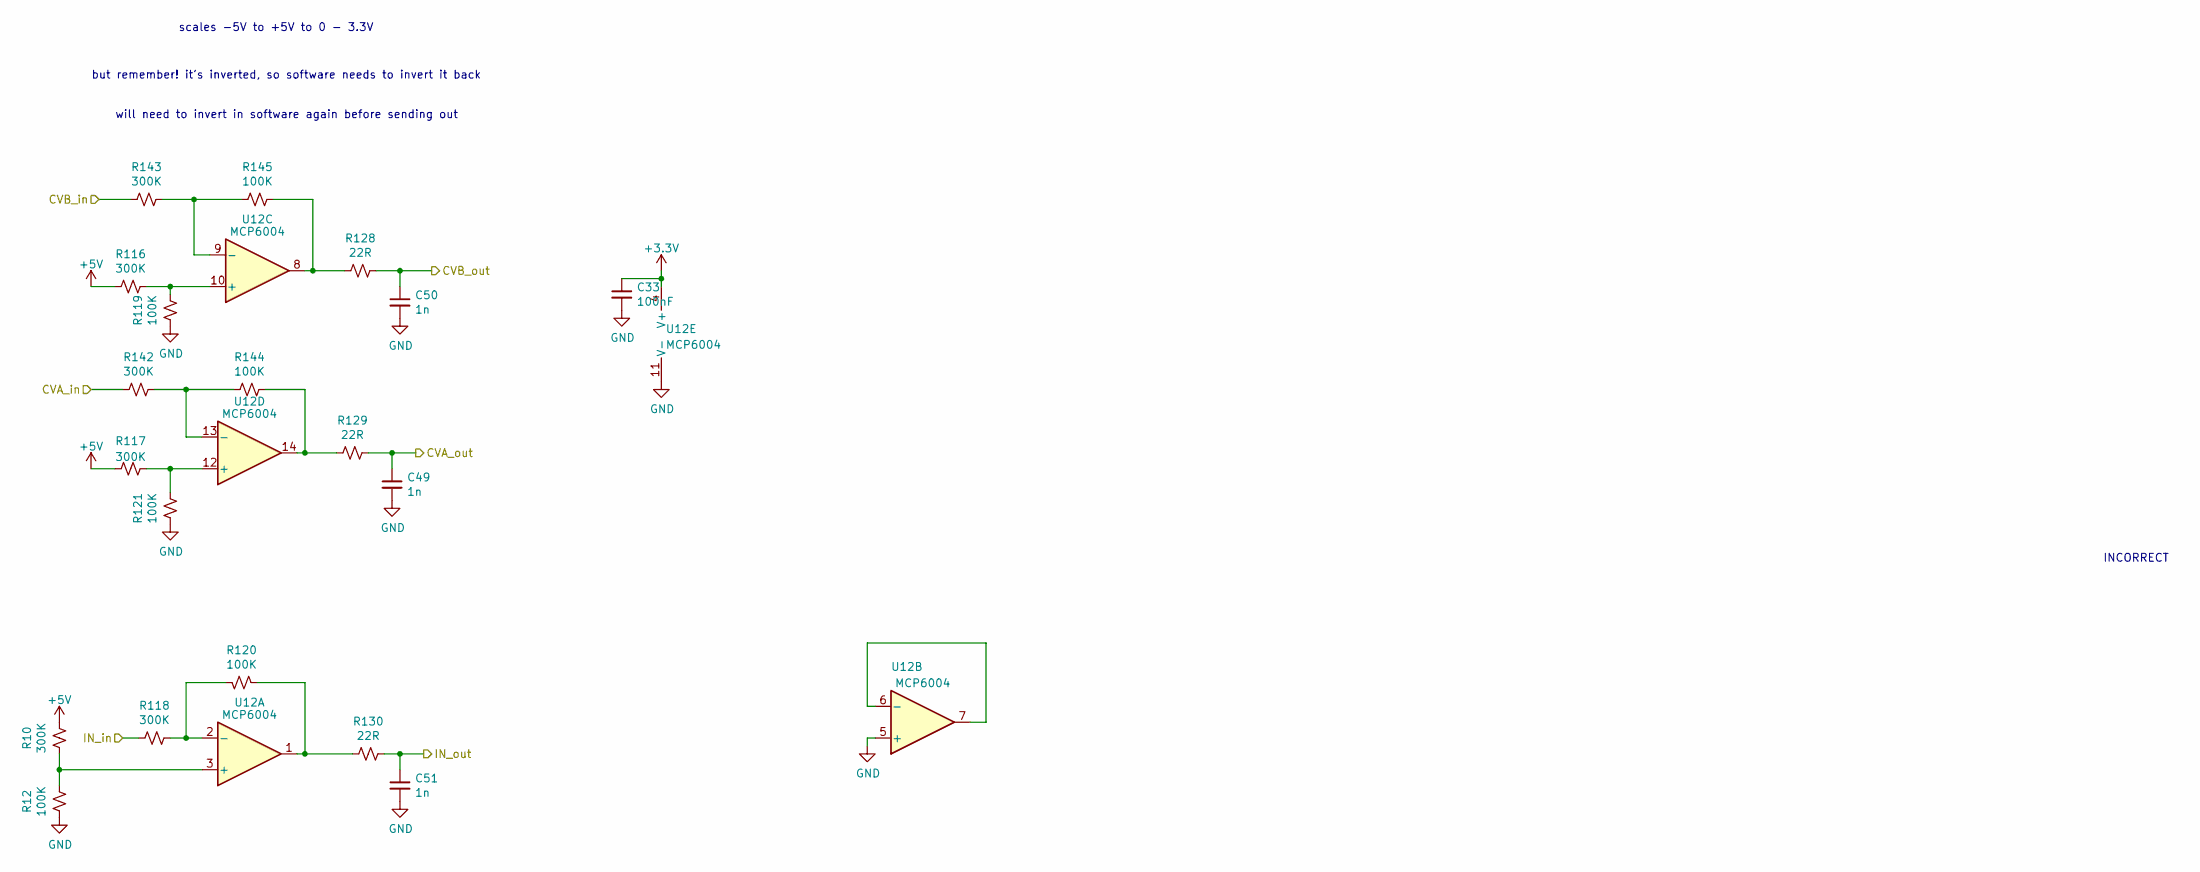
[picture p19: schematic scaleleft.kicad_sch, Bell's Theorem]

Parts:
C33: 100nF; C_0805_2012Metric_Pad1.18x1.45mm_HandSolder
C49, C50, C51: 1n; C_0805_2012Metric_Pad1.18x1.45mm_HandSolder
R10, R116, R117, R118, R142, R143: 300K; R_0805_2012Metric_Pad1.20x1.40mm_HandSolder
R12, R119, R120, R121, R144, R145: 100K; R_0805_2012Metric_Pad1.20x1.40mm_HandSolder
R128, R129, R130: 22R; R_0805_2012Metric_Pad1.20x1.40mm_HandSolder
U12: MCP6004; SO-14_3.9x8.65mm_P1.27mm

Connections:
+3V3: C33.1, U12.4 (V+); also elsewhere on the board
+5V: R10.1, R116.2, R117.2; also elsewhere on the board
/main/CVA: R142.2; also elsewhere on the board
/main/CVB: R143.2; also elsewhere on the board
/main/IN: R118.2; also elsewhere on the board
/main/scaleleft/CVA_out: C49.1, R129.1; also elsewhere on the board
/main/scaleleft/CVB_out: C50.1, R128.1; also elsewhere on the board
/main/scaleleft/IN_out: C51.1, R130.1; also elsewhere on the board
GND: C33.2, C49.2, C50.2, C51.2, R12.2, R119.2, R121.2, U12.5 (+), U12.11 (V-); also elsewhere on the board
unnamed: R10.2, R12.1, U12.3 (+)
unnamed: R116.1, R119.1, U12.10 (+)
unnamed: R117.1, R121.1, U12.12 (+)
unnamed: R118.1, R120.1, U12.2 (-)
unnamed: R120.2, R130.2, U12.1
unnamed: R128.2, R145.1, U12.8
unnamed: R129.2, R144.1, U12.14
unnamed: R142.1, R144.2, U12.13 (-)
unnamed: R143.1, R145.2, U12.9 (-)
unnamed: U12.6 (-), U12.7

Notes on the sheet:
INCORRECT
will need to invert in software again before sending out
scales -5V to +5V to 0 - 3.3V
but remember! it's inverted, so software needs to invert it back

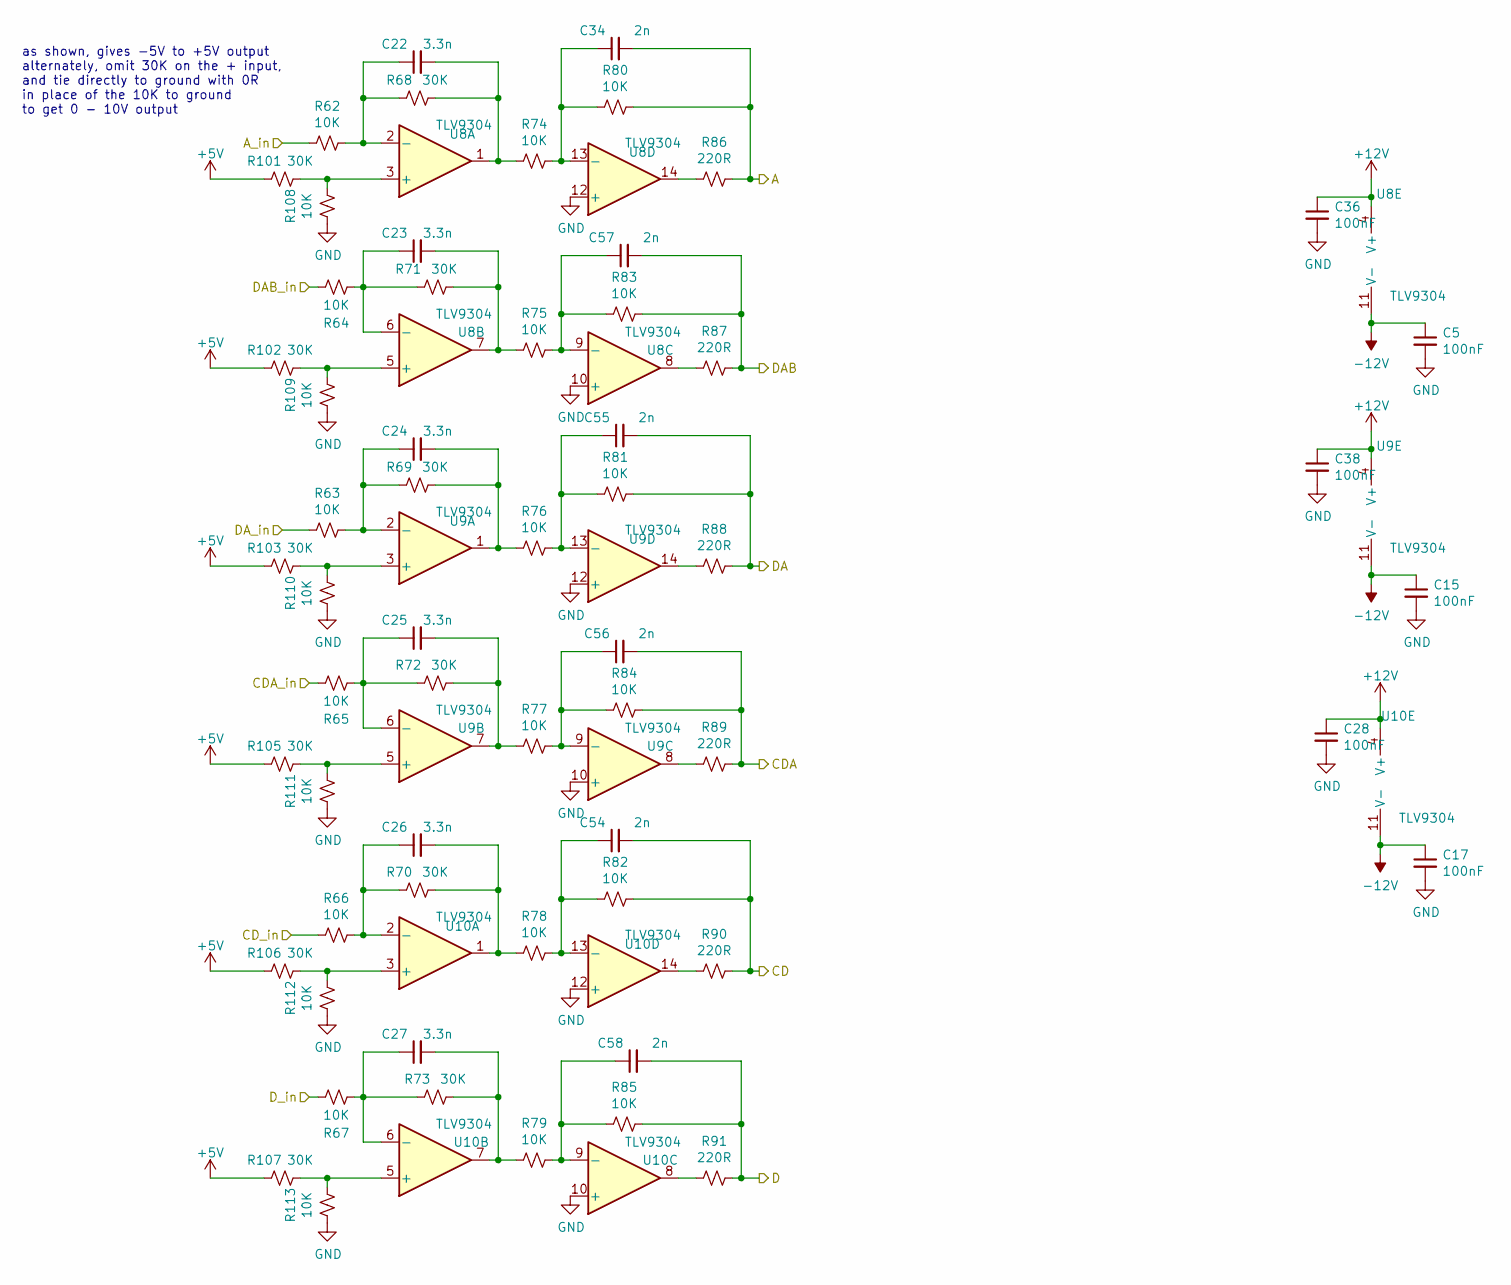
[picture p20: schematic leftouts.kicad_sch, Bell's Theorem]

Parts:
C5, C15, C17, C28, C36, C38: 100nF; C_0805_2012Metric_Pad1.18x1.45mm_HandSolder
C22, C23, C24, C25, C26, C27: 3.3n; C_0805_2012Metric_Pad1.18x1.45mm_HandSolder
C34, C54, C55, C56, C57, C58: 2n; C_0805_2012Metric_Pad1.18x1.45mm_HandSolder
R62, R63, R64, R65, R66, R67, R74, R75, R76, R77, R78, R79, R80, R81, R82, R83, R84, R85, R108, R109, R110, R111, R112, R113: 10K; R_0805_2012Metric_Pad1.20x1.40mm_HandSolder
R68, R69, R70, R71, R72, R73, R101, R102, R103, R105, R106, R107: 30K; R_0805_2012Metric_Pad1.20x1.40mm_HandSolder
R86, R87, R88, R89, R90, R91: 220R; R_0805_2012Metric_Pad1.20x1.40mm_HandSolder
U8, U9, U10: TLV9304; SOIC-14_3.9x8.7mm_P1.27mm

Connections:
+5V: R101.2, R102.2, R103.2, R105.2, R106.2, R107.2; also elsewhere on the board
+12V: C28.1, C36.1, C38.1, U8.4 (V+), U9.4 (V+), U10.4 (V+); also elsewhere on the board
-12V: C5.1, C15.1, C17.1, U8.11 (V-), U9.11 (V-), U10.11 (V-); also elsewhere on the board
/main/A: C34.2, R80.1, R86.1; also elsewhere on the board
/main/CD: C54.2, R82.1, R90.1; also elsewhere on the board
/main/CDA: C56.2, R84.1, R89.1; also elsewhere on the board
/main/D: C58.2, R85.1, R91.1; also elsewhere on the board
/main/DA: C55.2, R81.1, R88.1; also elsewhere on the board
/main/DAB: C57.2, R83.1, R87.1; also elsewhere on the board
/main/left outs/A_in: R62.2; also elsewhere on the board
/main/left outs/CDA_in: R65.2; also elsewhere on the board
/main/left outs/CD_in: R66.2; also elsewhere on the board
/main/left outs/DAB_in: R64.2; also elsewhere on the board
/main/left outs/DA_in: R63.2; also elsewhere on the board
/main/left outs/D_in: R67.2; also elsewhere on the board
GND: C5.2, C15.2, C17.2, C28.2, C36.2, C38.2, R108.2, R109.2, R110.2, R111.2, R112.2, R113.2, U8.10 (+), U8.12 (+), U9.10 (+), U9.12 (+), U10.10 (+), U10.12 (+); also elsewhere on the board
unnamed: C22.1, R62.1, R68.2, U8.2 (-)
unnamed: C22.2, R68.1, R74.2, U8.1
unnamed: C23.1, R64.1, R71.2, U8.6 (-)
unnamed: C23.2, R71.1, R75.2, U8.7
unnamed: C24.1, R63.1, R69.2, U9.2 (-)
unnamed: C24.2, R69.1, R76.2, U9.1
unnamed: C25.1, R65.1, R72.2, U9.6 (-)
unnamed: C25.2, R72.1, R77.2, U9.7
unnamed: C26.1, R66.1, R70.2, U10.2 (-)
unnamed: C26.2, R70.1, R78.2, U10.1
unnamed: C27.1, R67.1, R73.2, U10.6 (-)
unnamed: C27.2, R73.1, R79.2, U10.7
unnamed: C34.1, R74.1, R80.2, U8.13 (-)
unnamed: C54.1, R78.1, R82.2, U10.13 (-)
unnamed: C55.1, R76.1, R81.2, U9.13 (-)
unnamed: C56.1, R77.1, R84.2, U9.9 (-)
unnamed: C57.1, R75.1, R83.2, U8.9 (-)
unnamed: C58.1, R79.1, R85.2, U10.9 (-)
unnamed: R86.2, U8.14
unnamed: R87.2, U8.8
unnamed: R88.2, U9.14
unnamed: R89.2, U9.8
unnamed: R90.2, U10.14
unnamed: R91.2, U10.8
unnamed: R101.1, R108.1, U8.3 (+)
unnamed: R102.1, R109.1, U8.5 (+)
unnamed: R103.1, R110.1, U9.3 (+)
unnamed: R105.1, R111.1, U9.5 (+)
unnamed: R106.1, R112.1, U10.3 (+)
unnamed: R107.1, R113.1, U10.5 (+)

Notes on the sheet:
as shown, gives -5V to +5V output alternately, omit 30K on the + input, and tie directly to ground with 0R in place of the 10K to ground to get 0 - 10V output

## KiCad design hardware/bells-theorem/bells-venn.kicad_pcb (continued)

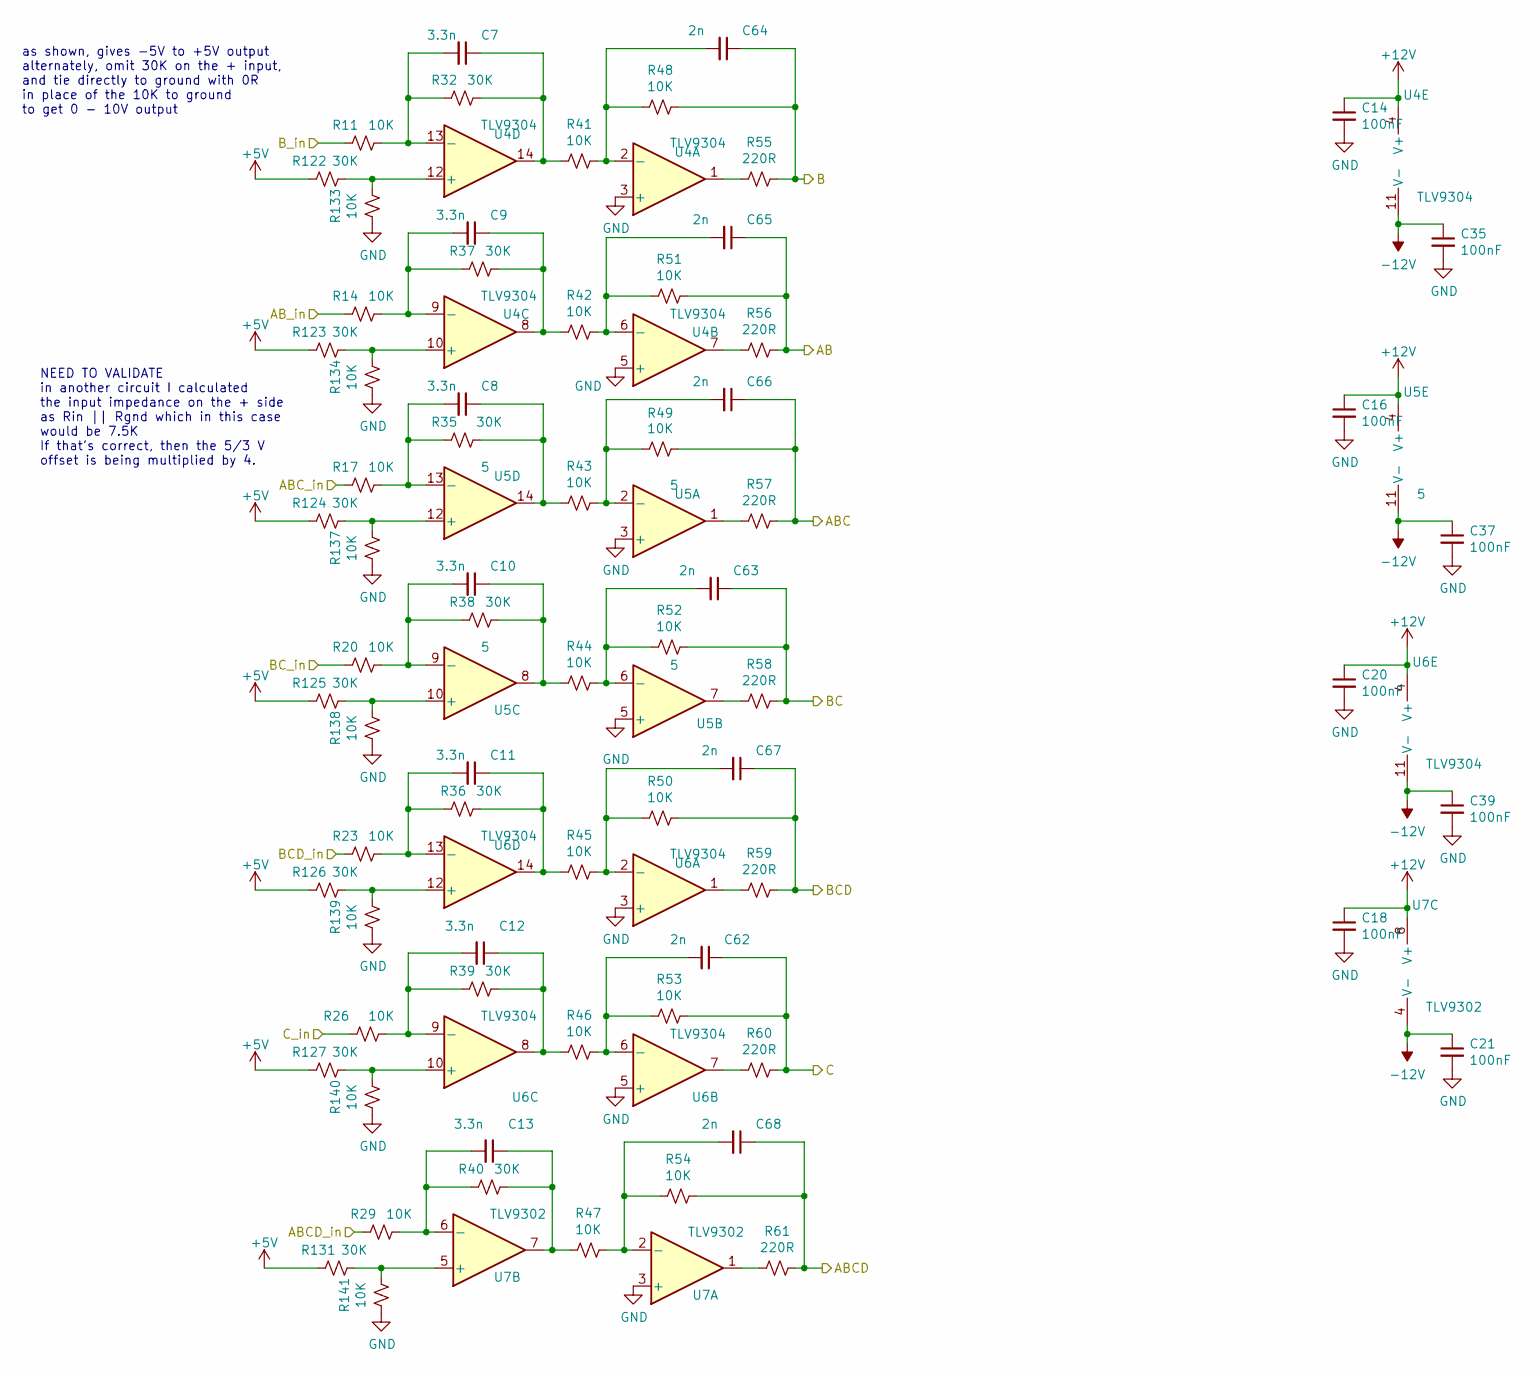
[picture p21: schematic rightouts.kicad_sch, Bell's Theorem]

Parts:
C7, C8, C9, C10, C11, C12, C13: 3.3n; C_0805_2012Metric_Pad1.18x1.45mm_HandSolder
C14, C16, C18, C20, C21, C35, C37, C39: 100nF; C_0805_2012Metric_Pad1.18x1.45mm_HandSolder
C62, C63, C64, C65, C66, C67, C68: 2n; C_0805_2012Metric_Pad1.18x1.45mm_HandSolder
R11, R14, R17, R20, R23, R26, R29, R41, R42, R43, R44, R45, R46, R47, R48, R49, R50, R51, R52, R53, R54, R133, R134, R137, R138, R139, R140, R141: 10K; R_0805_2012Metric_Pad1.20x1.40mm_HandSolder
R32, R35, R36, R37, R38, R39, R40, R122, R123, R124, R125, R126, R127, R131: 30K; R_0805_2012Metric_Pad1.20x1.40mm_HandSolder
R55, R56, R57, R58, R59, R60, R61: 220R; R_0805_2012Metric_Pad1.20x1.40mm_HandSolder
U4, U6: TLV9304; SOIC-14_3.9x8.7mm_P1.27mm
U5: 5; SOIC-14_3.9x8.7mm_P1.27mm
U7: TLV9302; SOIC-8_3.9x4.9mm_P1.27mm

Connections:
+5V: R122.2, R123.2, R124.2, R125.2, R126.2, R127.2, R131.2; also elsewhere on the board
+12V: C14.1, C16.1, C18.1, C20.1, U4.4 (V+), U5.4 (V+), U6.4 (V+), U7.8 (V+); also elsewhere on the board
-12V: C21.1, C35.1, C37.1, C39.1, U4.11 (V-), U5.11 (V-), U6.11 (V-), U7.4 (V-); also elsewhere on the board
/main/AB: C65.1, R51.1, R56.1; also elsewhere on the board
/main/ABC: C66.1, R49.1, R57.1; also elsewhere on the board
/main/ABCD: C68.1, R54.1, R61.1; also elsewhere on the board
/main/B: C64.1, R48.1, R55.1; also elsewhere on the board
/main/BC: C63.1, R52.1, R58.1; also elsewhere on the board
/main/BCD: C67.1, R50.1, R59.1; also elsewhere on the board
/main/C: C62.1, R53.1, R60.1; also elsewhere on the board
/main/right outs/ABCD_in: R29.2; also elsewhere on the board
/main/right outs/ABC_in: R17.2; also elsewhere on the board
/main/right outs/AB_in: R14.2; also elsewhere on the board
/main/right outs/BCD_in: R23.2; also elsewhere on the board
/main/right outs/BC_in: R20.2; also elsewhere on the board
/main/right outs/B_in: R11.2; also elsewhere on the board
/main/right outs/C_in: R26.2; also elsewhere on the board
GND: C14.2, C16.2, C18.2, C20.2, C21.2, C35.2, C37.2, C39.2, R133.2, R134.2, R137.2, R138.2, R139.2, R140.2, R141.2, U4.3 (+), U4.5 (+), U5.3 (+), U5.5 (+), U6.3 (+), U6.5 (+), U7.3 (+); also elsewhere on the board
unnamed: C7.1, R32.1, R41.2, U4.14
unnamed: C7.2, R11.1, R32.2, U4.13 (-)
unnamed: C8.1, R35.1, R43.2, U5.14
unnamed: C8.2, R17.1, R35.2, U5.13 (-)
unnamed: C9.1, R37.1, R42.2, U4.8
unnamed: C9.2, R14.1, R37.2, U4.9 (-)
unnamed: C10.1, R38.1, R44.2, U5.8
unnamed: C10.2, R20.1, R38.2, U5.9 (-)
unnamed: C11.1, R36.1, R45.2, U6.14
unnamed: C11.2, R23.1, R36.2, U6.13 (-)
unnamed: C12.1, R39.1, R46.2, U6.8
unnamed: C12.2, R26.1, R39.2, U6.9 (-)
unnamed: C13.1, R40.1, R47.2, U7.7
unnamed: C13.2, R29.1, R40.2, U7.6 (-)
unnamed: C62.2, R46.1, R53.2, U6.6 (-)
unnamed: C63.2, R44.1, R52.2, U5.6 (-)
unnamed: C64.2, R41.1, R48.2, U4.2 (-)
unnamed: C65.2, R42.1, R51.2, U4.6 (-)
unnamed: C66.2, R43.1, R49.2, U5.2 (-)
unnamed: C67.2, R45.1, R50.2, U6.2 (-)
unnamed: C68.2, R47.1, R54.2, U7.2 (-)
unnamed: R55.2, U4.1
unnamed: R56.2, U4.7
unnamed: R57.2, U5.1
unnamed: R58.2, U5.7
unnamed: R59.2, U6.1
unnamed: R60.2, U6.7
unnamed: R61.2, U7.1
unnamed: R122.1, R133.1, U4.12 (+)
unnamed: R123.1, R134.1, U4.10 (+)
unnamed: R124.1, R137.1, U5.12 (+)
unnamed: R125.1, R138.1, U5.10 (+)
unnamed: R126.1, R139.1, U6.12 (+)
unnamed: R127.1, R140.1, U6.10 (+)
unnamed: R131.1, R141.1, U7.5 (+)

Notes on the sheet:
NEED TO VALIDATE in another circuit I calculated the input impedance on the + side as Rin || Rgnd which in this case would be 7.5K If that's correct, then the 5/3 V offset is being multiplied by 4.
as shown, gives -5V to +5V output alternately, omit 30K on the + input, and tie directly to ground with 0R in place of the 10K to ground to get 0 - 10V output

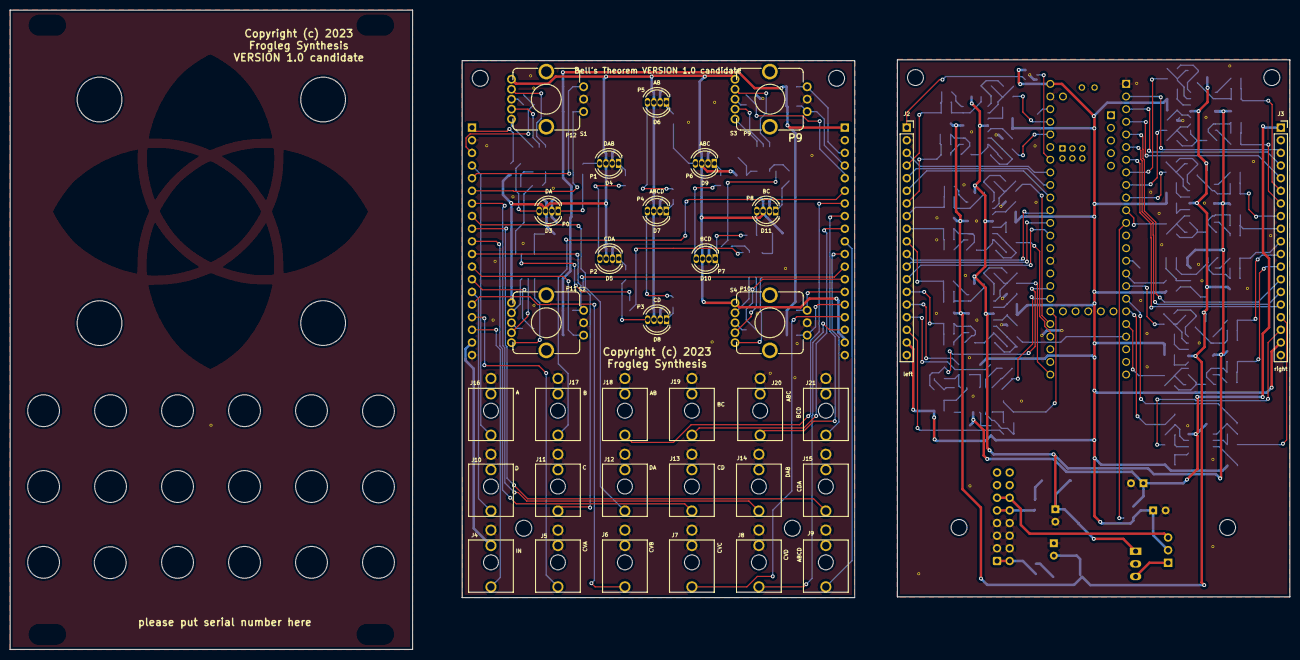
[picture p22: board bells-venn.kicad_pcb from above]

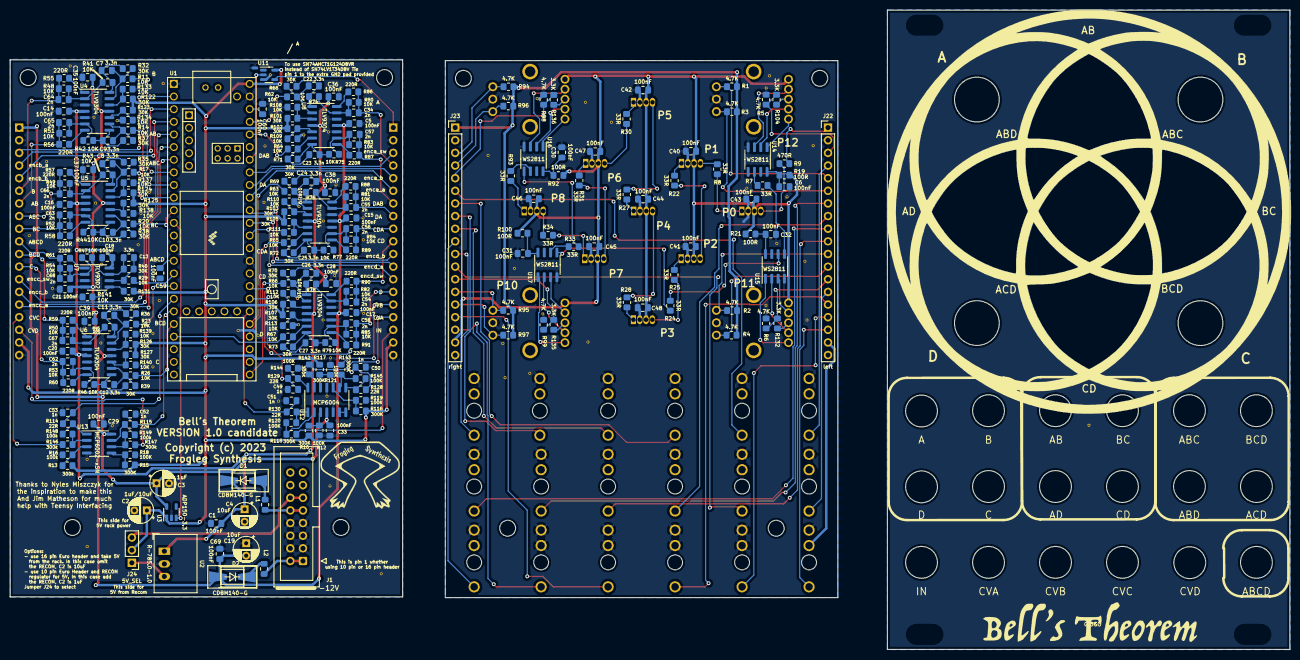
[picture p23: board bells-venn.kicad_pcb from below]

Board: 2 copper layers, 257.2 x 128.5 mm, 275 parts (242 on the bottom side), 190 nets.

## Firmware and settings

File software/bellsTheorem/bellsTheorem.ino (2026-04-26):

/*
 * Copyright (c) 2023 Frogleg Synthesis/Pete Hartman
 * 
 * Many thanks due to Jim Matheson for advice and coaching on how to work with Teensy, as well as some of the hardware details
 * This project wouldn't have been undertaken without the questions from Nyles Miszczyk on Facebook's Synth DIY group, about Bell's Theorem
 * 
 */

#include <Bounce2.h>
#include <EEPROM.h> // for saving state, eventually
//#include <Adafruit_NeoPixel.h>
// convert to use Paul's OctoWS2811 library instead
#include <OctoWS2811.h>
#include <ADC.h>
#include <IntervalTimer.h>

    
    /*                                                                *******
     * CHANGE THE RANGE TO MAP -5 - +5 to 0 - 3.3V instead of 0 - 10  *******
     *                                                                *******
     * Needs adjustments to the input op amps.                        *******
     */


/*
   EEPROM notes

   EEPROM.Put(address, object)
   EEPROM.Get(address, object)

   use sizeof(object) to increment the address
   no specific address map, just an array of bytes
*/

//#define DEBUG 1

// New revision of the board 0.4+ uses pin 20 as a NeoPixel serial control for the LEDs *including* the
// LEDs for the encoders (by way of WS2811 chips)
//

//  pins used
#define ENCAA 17
#define ENCAB 18
#define SWA 19
#define ENCBA 1
#define ENCBB 0
#define SWB 2
#define ENCCA 5
#define ENCCB 4
#define SWC 3
#define ENCDA 15
#define ENCDB 16
#define SWD 14
#define CVA A15
#define CVB A16
#define CVC A12
#define CVD A13
#define CV_IN A14
#define A 23
#define B 6
#define C 28
#define D 29
#define AB 7
#define BC 9
#define CD 33
#define DA 37
#define ABC 8
#define BCD 25
#define CDA 36
#define DAB 22
#define ABCD 24
#define NP 20
#define PC 13
#define ENA33 10

// fixed point, 3 digit representation of cosine squared, for integer angles 0 - 90
const unsigned short PROGMEM cos2Table[] = { // 3E8 == 1000 decimal
  0x3E8, 0x3E8, 0x3E6, 0x3E6, 0x3E4, 0x3E0, 0x3DE, 0x3DA, 0x3D4, 0x3D0,
  0x3CA, 0x3C4, 0x3BC, 0x3B5, 0x3AD, 0x3A5, 0x39C, 0x392, 0x388, 0x37F,
  0x374, 0x368, 0x35B, 0x350, 0x343, 0x335, 0x328, 0x31A, 0x30C, 0x2FE,
  0x2EE, 0x2DE, 0x2CF, 0x2C0, 0x2AF, 0x29F, 0x28E, 0x27E, 0x26D, 0x25C,
  0x24B, 0x23A, 0x228, 0x216, 0x205, 0x1F4, 0x1E3, 0x1D1, 0x1C0, 0x1AE,
  0x19D, 0x18C, 0x17B, 0x16A, 0x15A, 0x149, 0x138, 0x129, 0x119, 0x109,
  0xFA,  0xEB,  0xDC,  0xCE,  0xC0,  0xB3,  0xA6,  0x99,  0x8D,  0x80,
  0x75,  0x6A,  0x5F,  0x55,  0x4C,  0x43,  0x3B,  0x33,  0x2B,  0x24,
  0x1E,  0x18,  0x13,  0xF,   0xB,   0x8,   0x5,   0x3,   0x1,   0x0,   0x0
};

// Global variables for the encoders that are saved between calls:
const uint8_t encPins[8] = {ENCAA, ENCAB, ENCBA, ENCBB, ENCCA, ENCCB, ENCDA, ENCDB};//encoder pins defined above
static uint8_t enc_PrevNextCode[4] = {0, 0, 0, 0};//used by enc driver
static short enc_Store[4] = {0, 0, 0, 0};//used by enc driver
const bool ENC_DIRECTION = 0;//this can be changed in options for wrong way encoders

int enc_buttons[4] = { HIGH, HIGH, HIGH, HIGH }; //normal state
unsigned long enc_button_timers[4] = { 0, 0, 0, 0 };  // milliseconds need big numbers
byte enc_button_pins[4] = { SWA, SWB, SWC, SWD };
Bounce debA = Bounce();
Bounce debB = Bounce();
Bounce debC = Bounce();
Bounce debD = Bounce();
Bounce *debounce[4] = {&debA, &debB, &debC, &debD} ;

byte resolution = 10;
uint16_t maximumOutput = pow(2,resolution)-1;

// the following arrays all align
// value[0] corresponds to pinTable[0] corresponds to pixelTable[0]
// these are the actual value, the pin for the output to a jack, and the pixel number for an LED
// we start at 0 degrees, so everything is maxed out (until such time as we start taking input)
// first 4 are zero trying to take LEDs on the encoders out of the current draw
uint16_t value[13] = { maximumOutput, maximumOutput, maximumOutput, maximumOutput,
                    maximumOutput, maximumOutput, maximumOutput, maximumOutput,
                    maximumOutput, maximumOutput, maximumOutput, maximumOutput,
                    maximumOutput
                  };

// positions correspond to the value table
byte pinTable[13] = {
  A, B, C, D, AB, BC, CD, DA, ABC, BCD, CDA, DAB, ABCD
};

// 2023-03-16 pixel numbers are being shuffled because the WS2811 chips cannot come before
// any of the standalone LEDs; some brands (e.g. EMSL) of the LEDs don't work if they're
// positioned after the WS2811 chips.
//
// what are the pixel numbers of each position; now includes chip drivers for encoders
// the order below matches the hacked up re-ordered LED order, NOT the final version on PCB

// version 5 == 0.5, 6 == 0.6, presumably 10 will be 1.0 :)
#define hwversion 6

// 0.6 order
byte pixelTable[13] = {
  12, 9, 10, 11, 5, 8, 3, 0, 6, 7, 2, 1, 4
};



// WS2811 setup
// Any group of digital pins may be used
const int numPins = 1;
byte pinList[numPins] = {20};
const int ledsPerStrip = 13;

// These buffers need to be large enough for all the pixels.
// The total number of pixels is "ledsPerStrip * numPins".
// Each pixel needs 3 bytes, so multiply by 3.  An "int" is
// 4 bytes, so divide by 4.  The array is created using "int"
// so the compiler will align it to 32 bit memory.
DMAMEM int displayMemory[ledsPerStrip * numPins * 3 / 4];
int drawingMemory[ledsPerStrip * numPins * 3 / 4];


OctoWS2811 leds(ledsPerStrip, displayMemory, drawingMemory, WS2811_RGB | WS2811_800kHz, numPins, pinList);

// Pauls lib uses RGB absolute values rather than HSV and brightness

// base colors, need to scale for brightness
//#define RED    0xFF0000
//#define GREEN  0x00FF00
//#define BLUE   0x0000FF
//#define YELLOW 0xFFFF00
//#define PINK   0xFF1088
//#define ORANGE 0xE05800
//#define WHITE  0xFFFFFF
//
// decimal 75 (brightness determined previously, 75/255) is 0x4B
#define RED    0x4B0000
#define GREEN  0x004B00
#define BLUE   0x00004B
#define YELLOW 0x4B4B00
#define PINK   0x4B0528
#define ORANGE 0x471A00
#define WHITE  0x6B6B6B
// the knobs seem to need a bit more
#define BRIGHTWHITE 0x6B6B6B
#define knobBright 180
#define ledBright 120

int HueTable[13] = { YELLOW, BLUE, GREEN, RED, YELLOW, BLUE, GREEN, RED, YELLOW, BLUE, GREEN, RED, ORANGE }; 

uint16_t inputValue = maximumOutput;
uint16_t prevValue = maximumOutput;
boolean inChanged = false; // if nothing changes, why do any extra work?
boolean outChanged = false; // if nothing changes, why do any extra work?

const uint16_t angleScale = 2; // scale the encoder magnitude, otherwise you spend forever to go 180 degrees 
int16_t angle[4] = { 0, 0, 0, 0 };  // absolute angle of each encoder
int16_t prevAngle[4] = { 0, 0, 0, 0 }; // see if we changed
int16_t savedAngle[4] = { 0, 0, 0, 0 }; // "undo" of unintentional clicks
int16_t relativeAngle[6] = { 0, 0, 0, 0, 0, 0 }; // relative angle of each pair A->B, B->C, C->D, D->A, plus A->C and B->D
int16_t angle_sum[4] = { 0, 0, 0, 0 }; // hold angle + cv

IntervalTimer ioTimer, ctlTimer;

int brightness;  // since we are using "white" we need to be able to set this up at each byte of the RGB set and map to correct level

//
// ADC lib setup
//
byte inPins[5] = { CV_IN, CVA, CVB, CVC, CVD };
uint16_t inValues[5] = { 0, 0, 0, 0, 0 };
bool inFlags[5] = { false, false, false, false, false };

ADC *adc = new ADC();

void setup() {
  if (hwversion == 5) { // hw 0.5
    pixelTable[0] = 10;
    pixelTable[2] = 12; 
  } else { // right now just version 0.6
     // do nothing, we set it up correctly in the definition
  }
  
  // enable the 3.3V regulator!
  pinMode(ENA33, OUTPUT);
  digitalWrite(ENA33, HIGH);

  // set up for encoder button debouncing
  for (int i = 0; i < 4; i++) {
    debounce[i]->attach(enc_button_pins[i], INPUT);
    debounce[i]->interval(25); // 25ms debounce time
  }

  // analog write
  for (int i = 0; i < 13; i++) {
    analogWriteFrequency(pinTable[i], 146484.38); // was 146484.38
  }
  analogWriteResolution(resolution);

  // input setup
  for (int i = 0; i < 5; i++) {
    pinMode(inPins[i], INPUT); 
  }
  ////// ADC1 //////
  // Except for A16, the analog inputs I've selected only work with ADC1
  adc->adc1->setAveraging(16); // higher than 16 and we stall out
  adc->adc1->setResolution(resolution);
  // it can be any of the ADC_CONVERSION_SPEED enum: VERY_LOW_SPEED, LOW_SPEED, MED_SPEED, HIGH_SPEED_16BITS, HIGH_SPEED or VERY_HIGH_SPEED
  // see the documentation for more information
  // additionally the conversion speed can also be ADACK_2_4, ADACK_4_0, ADACK_5_2 and ADACK_6_2,
  // where the numbers are the frequency of the ADC clock in MHz and are independent on the bus speed.
  adc->adc1->setConversionSpeed(ADC_CONVERSION_SPEED::HIGH_SPEED); // change the conversion speed
  // it can be any of the ADC_MED_SPEED enum: VERY_LOW_SPEED, LOW_SPEED, MED_SPEED, HIGH_SPEED or VERY_HIGH_SPEED
  adc->adc1->setSamplingSpeed(ADC_SAMPLING_SPEED::HIGH_SPEED); // change the sampling speed
  // always call the compare functions after changing the resolution!
  //adc->adc0->enableCompare(1.0/3.3*adc->adc0->getMaxValue(), 0); // measurement will be ready if value < 1.0V
  //adc->adc0->enableCompareRange(1.0*adc->adc0->getMaxValue()/3.3, 2.0*adc->adc0->getMaxValue()/3.3, 0, 1); // ready if value lies out of [1.0,2.0] V
  // If you enable interrupts, notice that the isr will read the result, so that isComplete() will return false (most of the time)
  //adc->adc0->enableInterrupts(adc0_isr);
  adc->adc1->setReference(ADC_REFERENCE::REF_3V3); // probably the default
  adc->adc1->startSingleRead(inPins[0]);

  // for DEBUG if needed
  Serial.begin(115200);
  Serial.println("Bell's Theorem startup");
  Serial.print(F("F_CPU = "));
  Serial.print(F_CPU, DEC);
  Serial.println();
  Serial.println(maximumOutput);

  // OctoWS2811 library
  leds.begin();
  leds.show();

  // interrupt timers for main I/O and controls
  ioTimer.begin(doIO, 20.833); // was 20.833 for 48khz
  ioTimer.priority(10); // was 10
  ctlTimer.begin(getControl, 100); // was 333
  ctlTimer.priority(50); // was 50

  startupSeq(); // eventually something to blink lights and show we're alive
  Serial.println("startup done");
}

//
// model: 4 angles, main input
//    derived -> 13 output values
//
// view: analog write 13 values and display LEDs
//
// control: read encoders and CV ins, update angles
//          read main input and update
//
//   on control change, make update and kick the model to do the calculations
//
// 2022-01-16 currently core function complete, modified from above MVC:
//
// "view" analog read main input, write analog outputs
// "controller" read encoders and angle CVs, update angles
// "model" main loop, handle encoder switch presses, do the math if the input is changed, display the NeoPixels
//         display of the neopixels is in the main loop because 1) it's slower and 2) if the pretty lights lag the actual outputs a slight bit, not a big deal
//
// practical limits seem to be about 50Hz to have reasonable input/output correspondence.  
// 100Hz and higher tends to round off a direct output (input -> output without doing the math)
// There is about 1ms lag doing input -> output without the math


void loop() {
    // update button press
    for (int i=0; i < 4; i++) {
      debounce[i]->update();
      if (debounce[i]->fell()) {
        // Serial.print("got button press "); Serial.print(i); Serial.println();
        if (savedAngle[i] == 0) { // we don't have a saved angle
          savedAngle[i] = angle[i];
          angle[i] = 0;
        } else {  // we do have a saved angle, let's restore it
          angle[i] = savedAngle[i];
          savedAngle[i] = 0;
        }
        inChanged = true;
      }
    }
    // display output doesn't have to track as accurately as the actual output
    if (outChanged) {
      for (int i = 0; i < 13; i++ ) {
        if (i >=4) {
          brightness = (int)((value[i]>>4)*ledBright)/255; // *Bright values set up at the top to make
        } else { // knobs need a bit of a bump in brightness // easier to adjust
          brightness = (int)((value[i]>>4)*knobBright)/255;
        }
        leds.setPixel(pixelTable[i], brightness + (brightness<<8) + (brightness<<16));
        delayMicroseconds(250);
      }
      leds.show();
      outChanged = false;
    }
}


// abs(90 - abs( x - 90 )) reflects 0 - 180 to 0-90,90-0 and 0 - (-180) to the same
// need to make this a fake function define
// maybe this is wrong?
int16_t constrainCos2(int16_t angle) {
  return (abs(90 - abs(abs(angle) - 90)));
}

// should these be +/- 180 or 360 ?
int16_t constrainAngle(int16_t angle) {  // limit angles to -180 to +180 
  if (angle > 180) {
    angle -= 180;
  } else if (angle < -180) {
    angle += 180;
  }
  return (angle);
}

// funky modulus appropriate for wrapping at 0, instead of -modulus; good for wrapping around arrays
// no longer needed, unrolled loops
//int mod( int x, int y ){
//   return (x<0 ? ((x+1)%y)+y-1 : x%y);
//}

//You can make an intervaltimer and do lookups and update from that.
//that becomes your sample rate. say you wanted it to be 48khz, divide
//1 million by 48000, thats your interval. (it can be a float). I usually have
//a control loop timer running at about 3 khz, which reads the controls and
//translates them to values the audio rate timer can use, then the audio rate
//doesn’t have so much work to do. you can set the audio timer to high
//priority so other things don’t block it. -- JM 2021-10-05

void doIO() {  // violates the rules of "don't call other stuff"
  // set up to work with ADC library instead
  static byte current = 0;
  // if position[current] is ready read into the value array, set flag that it's valid, and increment current (with wrap)
  if ((inFlags[current] = adc->adc1->isComplete())) {
    // Serial.println("complete");
    //if (current != 0) { 
      inValues[current] = adc->adc1->readSingle();
    //} else { // don't invert main in (ONLY FOR REV 0.5+) <<< ? need to revisit this 
      inValues[current] = maximumOutput - inValues[current]; 
    //}
    current++;
    if (current > 4) {
      current = 0;
    }
  }
  if (inFlags[0]) {
    inputValue = (uint16_t)(inValues[0]);
    // inputValue = (uint16_t)(2 * abs(inValues[0] - (maximumOutput+1)/2));
    inFlags[0] = false;
  } 
  if ((inputValue != prevValue) || inChanged) {
    prevValue = inputValue;
    relativeAngle[0] = constrainAngle(angle_sum[1] - angle_sum[0]); // B - A
    relativeAngle[1] = constrainAngle(angle_sum[2] - angle_sum[1]); // C - B
    relativeAngle[2] = constrainAngle(angle_sum[3] - angle_sum[2]); // D - C
    relativeAngle[3] = constrainAngle(angle_sum[3] - angle_sum[0]); // D - A
    // now to do A->C and B->D for doing CDA (actually ACD) and DAB (actually ABD)
    relativeAngle[4] = constrainAngle(angle_sum[2] - angle_sum[0]); // C - A
    relativeAngle[5] = constrainAngle(angle_sum[3] - angle_sum[1]); // D - B  
    // A, B, C, D
    value[0] = (uint16_t)((inputValue * cos2Table[constrainCos2(angle_sum[0])]) / 1000); // VA = in * cos2(A)
    value[1] = (uint16_t)((inputValue * cos2Table[constrainCos2(angle_sum[1])]) / 1000); // VB = in * cos2(B)
    value[2] = (uint16_t)((inputValue * cos2Table[constrainCos2(angle_sum[2])]) / 1000); // VC = in * cos2(C)
    value[3] = (uint16_t)((inputValue * cos2Table[constrainCos2(angle_sum[3])]) / 1000); // VD = in * cos2(D)
    // AB, BC, CD, DA (AD)
    value[4] = (uint16_t)((value[0] * cos2Table[constrainCos2(relativeAngle[0])]) / 1000); // VAB = VA * cos2(AB)
    value[5] = (uint16_t)((value[1] * cos2Table[constrainCos2(relativeAngle[1])]) / 1000); // VBC = VB * cos2(BC)
    value[6] = (uint16_t)((value[2] * cos2Table[constrainCos2(relativeAngle[2])]) / 1000); // VCD = VC * cos2(CD)
    // position 7 is DA, should use A value * AD angle, not D value * AD angle
    value[7] = (uint16_t)((value[0] * cos2Table[constrainCos2(relativeAngle[3])]) / 1000); // VDA = VA * cos2(AD)
    // ABC, BCD, CDA (ACD), DAB (ABD)
    value[8] = (uint16_t)((value[4] * cos2Table[constrainCos2(relativeAngle[1])]) / 1000); // VABC = VAB * cos2(BC)
    value[9] = (uint16_t)((value[5] * cos2Table[constrainCos2(relativeAngle[2])]) / 1000); // VBCD = VBC * cos2(CD)
    // AC is special, there is no intermediate AC created before this                      VCDA = VACD = VA * cos2(AC) * cos2(CD)
    value[10] = (uint16_t)((value[0] * cos2Table[constrainCos2(relativeAngle[4])] * cos2Table[constrainCos2(relativeAngle[2])]) / 1000000); // is this overflowing?
    value[11] = (uint16_t)((value[4] * cos2Table[constrainCos2(relativeAngle[5])]) / 1000); // VDAB = VABD = VAB * cos2(BD)
    value[12] = (uint16_t)((value[8] * cos2Table[constrainCos2(relativeAngle[2])]) / 1000); // VABCD = VABC * cos2(CD)
    outChanged = true;
    inChanged = false;
    for (int i = 0; i < 13; i++) { 
      analogWrite(pinTable[i], value[i]);
    }
  }
  // start analogRead of [current] which has been incremented above
  adc->adc1->startSingleRead(inPins[current]);
  // angle CV ins are read in getControl, alongside rotary positions
}

/*
 * Input protection with the MCP600X chips changes my input range to -10V = 0, 0V = half, 10V = full 
 * ... except I don't think it does  I'm dividing the input /3 and buffering it with the 0 - 3.3V op amps
 */
void getControl() {
    for (int k=0; k<4; k++) { // looping through the values table
      angle[k] = constrainAngle(angle[k] + read_rotary(k) * angleScale); // angle[k] has the "absolute" angle of that encoder
      if (inFlags[k+1]) {
        angle_sum[k] = constrainAngle((inValues[k+1] * 180 / maximumOutput) + angle[k]);
        if (angle_sum[k] != prevAngle[k]) {
          prevAngle[k] = angle_sum[k];
          inChanged = true;
        }
        inFlags[k+1] = false;
      }
    }
}


// Jim Matheson's encoder driver
// A vald CW or  CCW move returns 1 or -1 , invalid returns 0.
// adapted from original code by John Main - best-microcontroller-projects.com
int8_t read_rotary(uint8_t num) {
  static int8_t rot_enc_table[] = {0, 1, 1, 0, 1, 0, 0, 1, 1, 0, 0, 1, 0, 1, 1, 0};

  enc_PrevNextCode[num] <<= 2;
  if (!ENC_DIRECTION) { //forward
    if (digitalReadFast(encPins[num << 1])) enc_PrevNextCode[num] |= 0x02;
    if (digitalReadFast(encPins[(num << 1) + 1])) enc_PrevNextCode[num] |= 0x01;
  } else {//reverse
    if (digitalReadFast(encPins[num << 1])) enc_PrevNextCode[num] |= 0x02;
    if (digitalReadFast(encPins[(num << 1) + 1])) enc_PrevNextCode[num] |= 0x01;
  }
  enc_PrevNextCode[num] &= 0x0f;

  // If valid then store as 16 bit data.
  if  (rot_enc_table[enc_PrevNextCode[num]] ) {
    enc_Store[num] <<= 4;
    enc_Store[num] |= enc_PrevNextCode[num];
    if ((enc_Store[num] & 0xff) == 0x2b) return 1;
    if ((enc_Store[num] & 0xff) == 0x17) return -1;
  }
  return 0;
}

void startupSeq() {
  for (int i = 0; i < 13; i++) {
    leds.setPixel(pixelTable[i], HueTable[i]);
    leds.show();
    Serial.println(pixelTable[i]);
    delayMicroseconds(250000); //
  }
  delayMicroseconds(250000000);
  for (int i = 0; i < 13; i++) {
    leds.setPixel(pixelTable[i], 0);
    leds.show();
    delayMicroseconds(200);
  }
  return;
}


//notes on ADC pins
//const uint8_t pin_to_channel[] = { // pg 482
//        7,      // 0/A0  AD_B1_02
//        8,      // 1/A1  AD_B1_03
//        12,     // 2/A2  AD_B1_07
//        11,     // 3/A3  AD_B1_06
//        6,      // 4/A4  AD_B1_01
//        5,      // 5/A5  AD_B1_00
//        15,     // 6/A6  AD_B1_10
//        0,      // 7/A7  AD_B1_11
//        13,     // 8/A8  AD_B1_08
//        14,     // 9/A9  AD_B1_09
//        1,      // 24/A10 AD_B0_12 - maybe only on ADC0
//        2,      // 25/A11 AD_B0_13 - maybe only on ADC0
//        128+3,  // 26/A12 AD_B1_14 - only on ADC1, 3
//        128+4,  // 27/A13 AD_B1_15 - only on ADC1, 4
//        7,      // 14/A0  AD_B1_02
//        8,      // 15/A1  AD_B1_03
//        12,     // 16/A2  AD_B1_07
//        11,     // 17/A3  AD_B1_06
//        6,      // 18/A4  AD_B1_01
//        5,      // 19/A5  AD_B1_00
//        15,     // 20/A6  AD_B1_10
//        0,      // 21/A7  AD_B1_11
//        13,     // 22/A8  AD_B1_08
//        14,     // 23/A9  AD_B1_09
//        1,      // 24/A10 AD_B0_12
//        2,      // 25/A11 AD_B0_13
//        128+3,  // 26/A12 AD_B1_14 - only on ADC1, 3
//        128+4,  // 27/A13 AD_B1_15 - only on ADC1, 4
//#ifdef ARDUINO_TEENSY41
//        255,    // 28
//        255,    // 29
//        255,    // 30
//        255,    // 31
//        255,    // 32
//        255,    // 33
//        255,    // 34
//        255,    // 35
//        255,    // 36
//        255,    // 37
//        128+1,  // 38/A14 AD_B1_12 - only on ADC1, 1
//        128+2,  // 39/A15 AD_B1_13 - only on ADC1, 2
//        9,      // 40/A16 AD_B1_04
//        10,     // 41/A17 AD_B1_05
//#endif
//};

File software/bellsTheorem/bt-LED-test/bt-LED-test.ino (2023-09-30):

#include <Bounce2.h>
#include <EEPROM.h> // for saving state, eventually
//#include <Adafruit_NeoPixel.h>
// convert to use Paul's OctoWS2811 library instead
#include <OctoWS2811.h>
#include <ADC.h>
#include <IntervalTimer.h>


/*
   EEPROM notes

   EEPROM.Put(address, object)
   EEPROM.Get(address, object)

   use sizeof(object) to increment the address
   no specific address map, just an array of bytes
*/

//#define DEBUG 1

// New revision of the board 0.4+ uses pin 20 as a NeoPixel serial control for the LEDs *including* the
// LEDs for the encoders (by way of WS2811 chips)
//

//  pins used
#define ENCAA 17
#define ENCAB 18
#define SWA 19
#define ENCBA 1
#define ENCBB 0
#define SWB 2
#define ENCCA 5
#define ENCCB 4
#define SWC 3
#define ENCDA 15
#define ENCDB 16
#define SWD 14
#define CVA A15
#define CVB A16
#define CVC A12
#define CVD A13
#define CV_IN A14
#define A 23
#define B 6
#define C 28
#define D 29
#define AB 7
#define BC 9
#define CD 33
#define DA 37
#define ABC 8
#define BCD 25
#define CDA 36
#define DAB 22
#define ABCD 24
#define NP 20
// there are 9, but in the prototype there's an extra one used for level shifting (???)
#define PC 13
#define ENA33 10




// stuff for bell's Theorem testing
// fixed point, 3 digit representation of cosine squared, for integer angles 0 - 90
const unsigned short PROGMEM cos2Table[] = { // 3E8 == 1000 decimal
  0x3E8,0x3E8,0x3E6,0x3E6,0x3E4,0x3E0,0x3DE,0x3DA,0x3D4,0x3D0,
  0x3CA,0x3C4,0x3BC,0x3B5,0x3AD,0x3A5,0x39C,0x392,0x388,0x37F,
  0x374,0x368,0x35B,0x350,0x343,0x335,0x328,0x31A,0x30C,0x2FE,
  0x2EE,0x2DE,0x2CF,0x2C0,0x2AF,0x29F,0x28E,0x27E,0x26D,0x25C,
  0x24B,0x23A,0x228,0x216,0x205,0x1F4,0x1E3,0x1D1,0x1C0,0x1AE,
  0x19D,0x18C,0x17B,0x16A,0x15A,0x149,0x138,0x129,0x119,0x109,
  0xFA,0xEB,0xDC,0xCE,0xC0,0xB3,0xA6,0x99,0x8D,0x80,
  0x75,0x6A,0x5F,0x55,0x4C,0x43,0x3B,0x33,0x2B,0x24,
  0x1E,0x18,0x13,0xF,0xB,0x8,0x5,0x3,0x1,0x0,0x0
};


// Gamma brightness lookup table <https://victornpb.github.io/gamma-table-generator>
// gamma = 2.5 steps = 1024 range = 0-1023
const uint16_t PROGMEM gamma10[] = {
     0,   0,   0,   0,   0,   0,   0,   0,   0,   0,   0,   0,   0,   0,   0,   0,
     0,   0,   0,   0,   0,   0,   0,   0,   0,   0,   0,   0,   0,   0,   0,   0,
     0,   0,   0,   0,   0,   0,   0,   0,   0,   0,   0,   0,   0,   0,   0,   0,
     0,   1,   1,   1,   1,   1,   1,   1,   1,   1,   1,   1,   1,   1,   1,   1,
     1,   1,   1,   1,   1,   1,   1,   1,   1,   1,   1,   1,   2,   2,   2,   2,
     2,   2,   2,   2,   2,   2,   2,   2,   2,   2,   2,   2,   2,   3,   3,   3,
     3,   3,   3,   3,   3,   3,   3,   3,   3,   3,   4,   4,   4,   4,   4,   4,
     4,   4,   4,   4,   4,   5,   5,   5,   5,   5,   5,   5,   5,   5,   5,   6,
     6,   6,   6,   6,   6,   6,   6,   6,   7,   7,   7,   7,   7,   7,   7,   7,
     8,   8,   8,   8,   8,   8,   8,   9,   9,   9,   9,   9,   9,   9,  10,  10,
    10,  10,  10,  10,  11,  11,  11,  11,  11,  11,  12,  12,  12,  12,  12,  12,
    13,  13,  13,  13,  13,  13,  14,  14,  14,  14,  14,  15,  15,  15,  15,  15,
    16,  16,  16,  16,  16,  17,  17,  17,  17,  18,  18,  18,  18,  18,  19,  19,
    19,  19,  20,  20,  20,  20,  20,  21,  21,  21,  21,  22,  22,  22,  22,  23,
    23,  23,  23,  24,  24,  24,  25,  25,  25,  25,  26,  26,  26,  26,  27,  27,
    27,  28,  28,  28,  28,  29,  29,  29,  30,  30,  30,  31,  31,  31,  31,  32,
    32,  32,  33,  33,  33,  34,  34,  34,  35,  35,  35,  36,  36,  36,  37,  37,
    37,  38,  38,  38,  39,  39,  39,  40,  40,  40,  41,  41,  42,  42,  42,  43,
    43,  43,  44,  44,  45,  45,  45,  46,  46,  46,  47,  47,  48,  48,  48,  49,
    49,  50,  50,  50,  51,  51,  52,  52,  53,  53,  53,  54,  54,  55,  55,  56,
    56,  56,  57,  57,  58,  58,  59,  59,  60,  60,  60,  61,  61,  62,  62,  63,
    63,  64,  64,  65,  65,  66,  66,  67,  67,  68,  68,  69,  69,  70,  70,  71,
    71,  72,  72,  73,  73,  74,  74,  75,  75,  76,  76,  77,  77,  78,  78,  79,
    79,  80,  80,  81,  82,  82,  83,  83,  84,  84,  85,  85,  86,  87,  87,  88,
    88,  89,  89,  90,  91,  91,  92,  92,  93,  94,  94,  95,  95,  96,  97,  97,
    98,  98,  99, 100, 100, 101, 102, 102, 103, 103, 104, 105, 105, 106, 107, 107,
   108, 109, 109, 110, 110, 111, 112, 112, 113, 114, 114, 115, 116, 117, 117, 118,
   119, 119, 120, 121, 121, 122, 123, 123, 124, 125, 126, 126, 127, 128, 128, 129,
   130, 131, 131, 132, 133, 133, 134, 135, 136, 136, 137, 138, 139, 139, 140, 141,
   142, 143, 143, 144, 145, 146, 146, 147, 148, 149, 149, 150, 151, 152, 153, 153,
   154, 155, 156, 157, 158, 158, 159, 160, 161, 162, 162, 163, 164, 165, 166, 167,
   167, 168, 169, 170, 171, 172, 173, 173, 174, 175, 176, 177, 178, 179, 180, 180,
   181, 182, 183, 184, 185, 186, 187, 188, 188, 189, 190, 191, 192, 193, 194, 195,
   196, 197, 198, 199, 200, 200, 201, 202, 203, 204, 205, 206, 207, 208, 209, 210,
   211, 212, 213, 214, 215, 216, 217, 218, 219, 220, 221, 222, 223, 224, 225, 226,
   227, 228, 229, 230, 231, 232, 233, 234, 235, 236, 237, 238, 239, 240, 241, 242,
   243, 244, 245, 247, 248, 249, 250, 251, 252, 253, 254, 255, 256, 257, 258, 260,
   261, 262, 263, 264, 265, 266, 267, 268, 270, 271, 272, 273, 274, 275, 276, 277,
   279, 280, 281, 282, 283, 284, 286, 287, 288, 289, 290, 291, 293, 294, 295, 296,
   297, 298, 300, 301, 302, 303, 304, 306, 307, 308, 309, 311, 312, 313, 314, 315,
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
  };

// ^^ unused ?


// Global variables for the encoders that are saved between calls:
const uint8_t encPins[8] = {ENCAA, ENCAB, ENCBA, ENCBB, ENCCA, ENCCB, ENCDA, ENCDB};//encoder pins defined above
static uint8_t enc_PrevNextCode[4] = {0, 0, 0, 0};//used by enc driver
static uint16_t enc_Store[4] = {0, 0, 0, 0};//used by enc driver
const bool ENC_DIRECTION = 0;//this can be changed in options for wrong way encoders

int enc_buttons[4] = { HIGH, HIGH, HIGH, HIGH }; //normal state
unsigned long enc_button_timers[4] = { 0, 0, 0, 0 };  // milliseconds need big numbers
byte enc_button_pins[4] = { SWA, SWB, SWC, SWD };
Bounce debA=Bounce();
Bounce debB=Bounce();
Bounce debC=Bounce();
Bounce debD=Bounce();
Bounce *debounce[4] = {&debA, &debB, &debC, &debD} ; 

byte cv_in_pins[4] = { CVA, CVB, CVC, CVD };
long cv_values[4] = { 0, 0, 0, 0 };

byte resolution = 10;
const unsigned short maximumOutput = 0x3FF; //1023
// we start at 0 degrees, so everything is maxed out (until such time as we start taking input)
short value[13] = { maximumOutput, maximumOutput, maximumOutput, maximumOutput,
                    maximumOutput, maximumOutput, maximumOutput, maximumOutput,
                    maximumOutput, maximumOutput, maximumOutput, maximumOutput,
                    maximumOutput };
// positions correspond to the value table
byte pinTable[13] = {
  A, B, C, D, AB, BC, CD, DA, ABC, BCD, CDA, DAB, ABCD
};

// what are the pixel numbers of each position; now includes chip drivers for encoders
byte pixelTable[13] = {
  0, 12, 10, 4, 7, 11, 5, 1, 8, 9, 3, 2, 6
};
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

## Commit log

2020-10-23 Standard Teensy Encoder library (lots of jitter)
    [bellsTheorem.ino]
2020-10-24 Updated with Jim Matheson's encoder driver
2020-10-24 added debounced switch behavior (save current angle and reset to 0 degrees, press again and restore that previous angle)
    [bellsTheorem.ino]
2020-10-29 add the kicad files
    [bells-venn-B_Cu.gbr, bells-venn-B_Mask.gbr, bells-venn-B_Paste.gbr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]
2021-03-29 take gerbers out of the repo, push latest updates
    [bells-venn-B_Cu.gbr, bells-venn-B_Mask.gbr, bells-venn-B_Paste.gbr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]
2021-03-30 revised LED drivers for encoders, fixed code in various places
    [bells-venn.kicad_pcb, panel.sch]
2021-03-30 testing token
    [panel.sch]
2021-05-05 version 0.3, update for corrected LED drivers, other tweaks
    [bells-venn.kicad_pcb, bells-venn.sch, main.sch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]
2021-10-01 updated for NeoPixels
    [bells-venn-B_Cu.gbr, bells-venn-B_Mask.gbr, bells-venn-B_Paste.gbr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]
2021-10-06 last changes before major rework into JM's suggested MVC type architecture
    [bellsTheorem.ino]
2022-01-16 modified for Kicad 6 updated testing code
    [bells-venn.kicad_pcb, main.sch, panel.sch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]
2022-01-16 updates to reflect KiCad 6 library changes revised level shifting for NeoPixels
    [bells-venn.kicad_sch, leftouts.kicad_sch, main.kicad_sch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]
2022-01-17 Modified with Jim M's recommendations for input scaling
    [bells-venn.kicad_pcb, bells-venn.kicad_sch, leftouts.kicad_sch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]
2022-01-17 All changes up to date with latest revisions
    [bells-venn.kicad_pcb, bells-venn.kicad_sch, leftouts.kicad_sch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]
2022-01-17 use new interrupt methods and do calculations core functionality complete
    [bells-venn.kicad_pcb]
2022-09-14 last hardware / software updates
    [bells-venn-B_Cu.gbr, bells-venn-B_Mask.gbr, bells-venn-B_Paste.gbr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]
2022-11-29 deleting gerbers
    [bells-venn-B_Cu.gbr, bells-venn-B_Mask.gbr, bells-venn-B_Paste.gbr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]
2023-09-30 version 0.6 hardware and code
    [bells-venn-B_Cu.gbr, bells-venn-B_Mask.gbr, bells-venn-B_Paste.gbr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]
2023-11-29 current revision actually 0.6 was 1.0 candidate, but needs major revision
    [bells-venn.kicad_sch, leftouts.kicad_sch, main.kicad_sch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]
2026-04-26 checking in old outstanding changes prior to debugging with Claude Code
    [bells-venn.kicad_pcb, bells-venn.kicad_sch, leftouts.kicad_sch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]

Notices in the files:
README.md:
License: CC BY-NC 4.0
